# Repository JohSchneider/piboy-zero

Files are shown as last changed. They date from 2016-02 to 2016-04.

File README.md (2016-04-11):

# Pi-Boy Zero
aka "PiGrrl-Zero"

[hackaday.io project](https://hackaday.io/project/9467-pigrrl-zero)

*yet another portable console! ;-)*

roughly the size of a gameboy micro, with a 2.2" display

this repository holds:
- the pcb-schematics (kicad)
- stl files for a 3d printable case
- and various setup scripts/tools/config-files to get emulationstation running on this particular hardware setup

## the progress so far
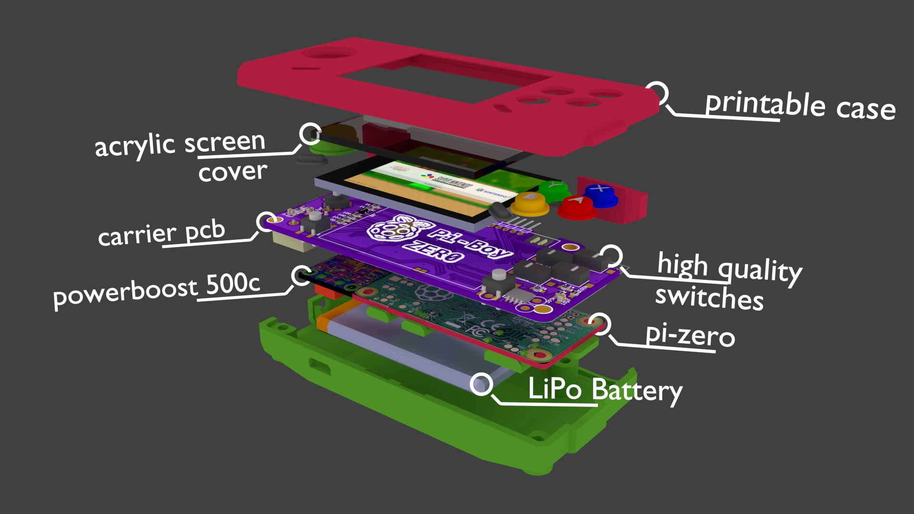
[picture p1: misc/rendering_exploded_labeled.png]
rendering of how the components are assembled

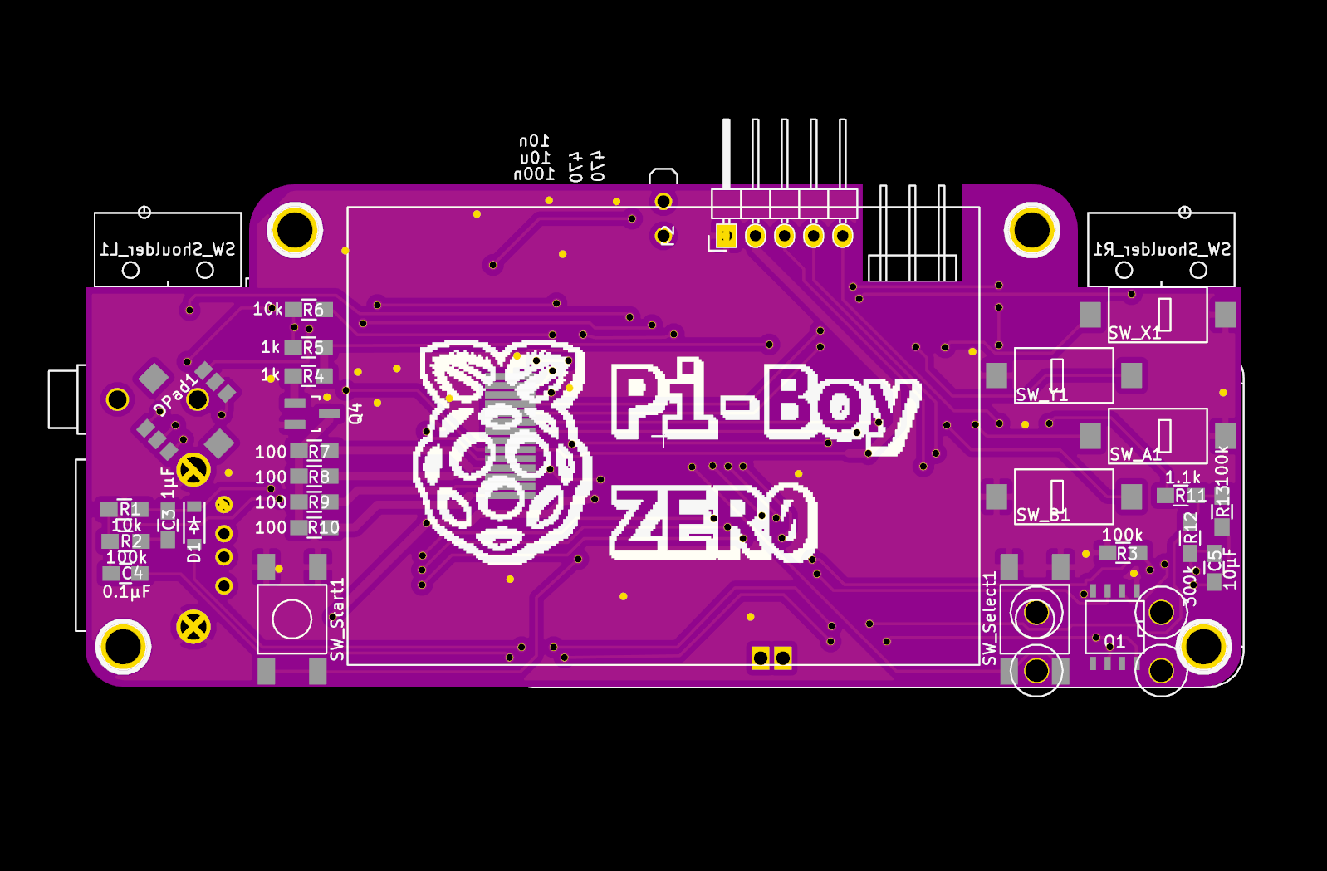
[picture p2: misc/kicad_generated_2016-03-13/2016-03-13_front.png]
front face of the carrier pcb

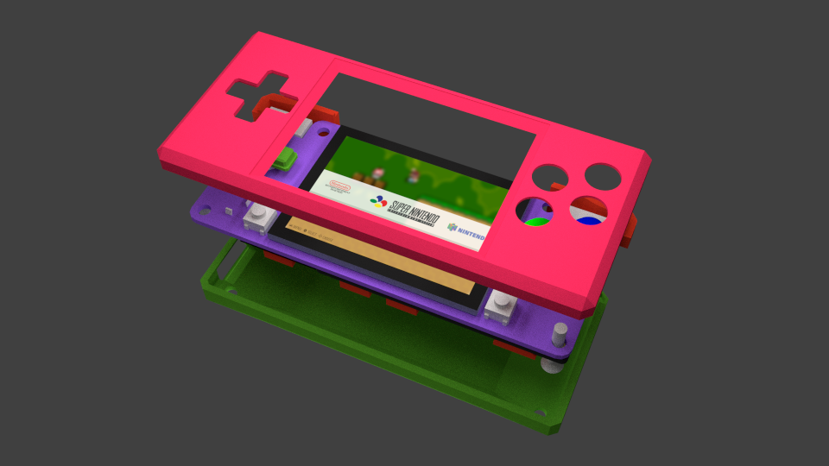
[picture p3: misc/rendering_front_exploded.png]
rendering of what the 3d printed case will look like

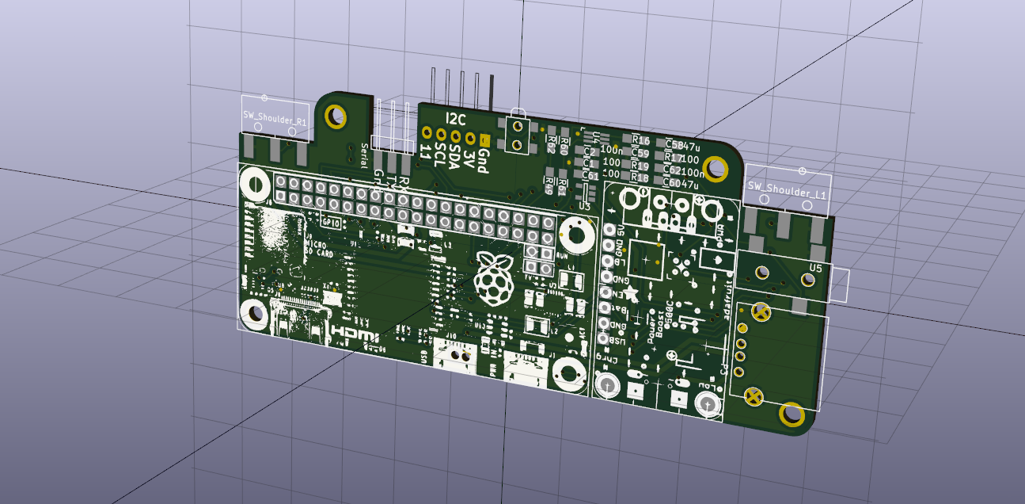
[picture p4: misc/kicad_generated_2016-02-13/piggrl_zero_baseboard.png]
kicad rendering of the baseboard


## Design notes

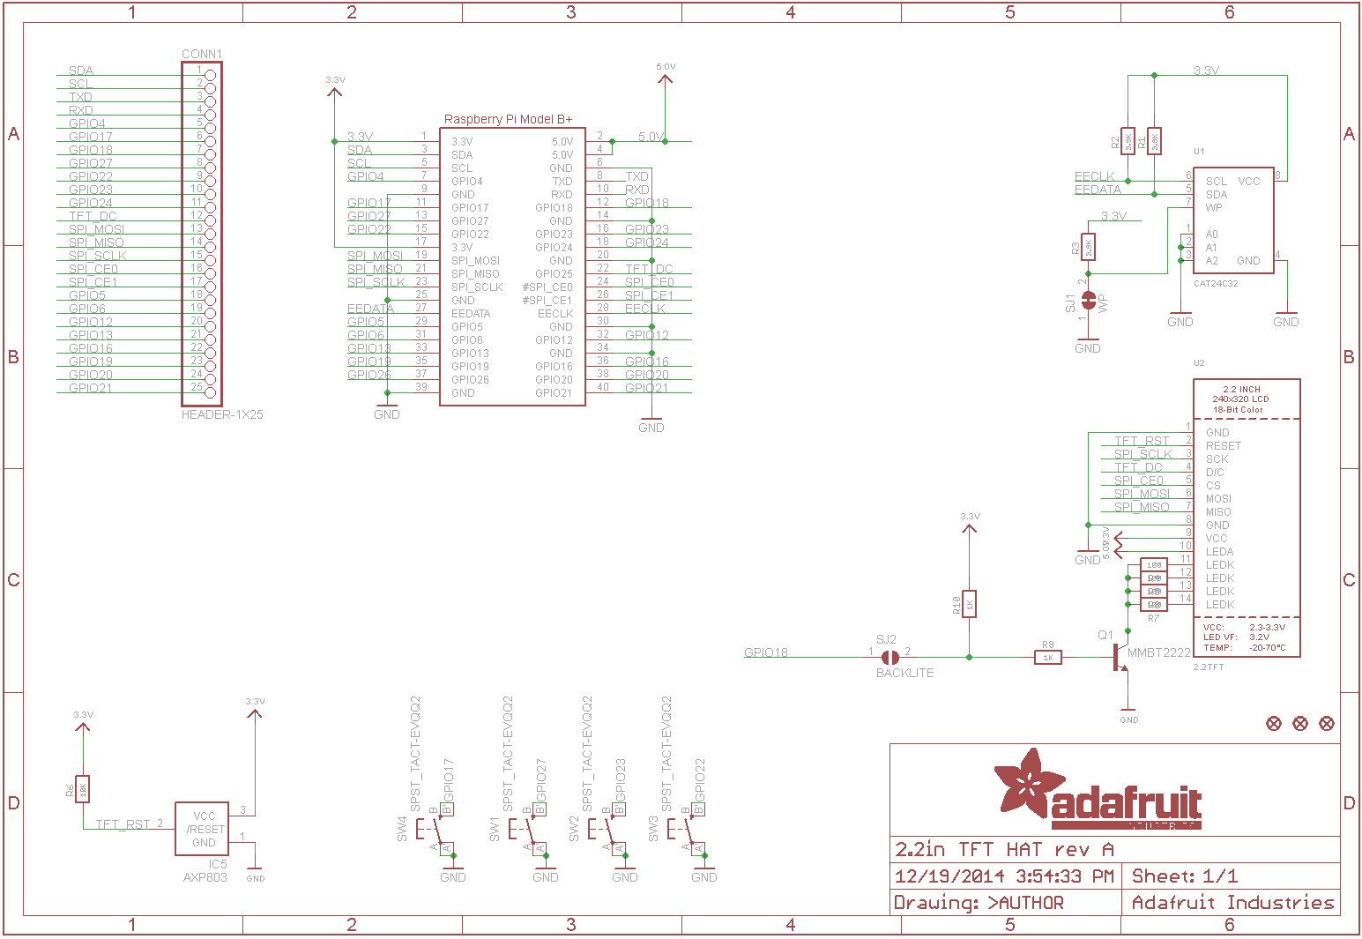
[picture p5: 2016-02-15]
source_schematics/pitftf_2.2inch_hat.png

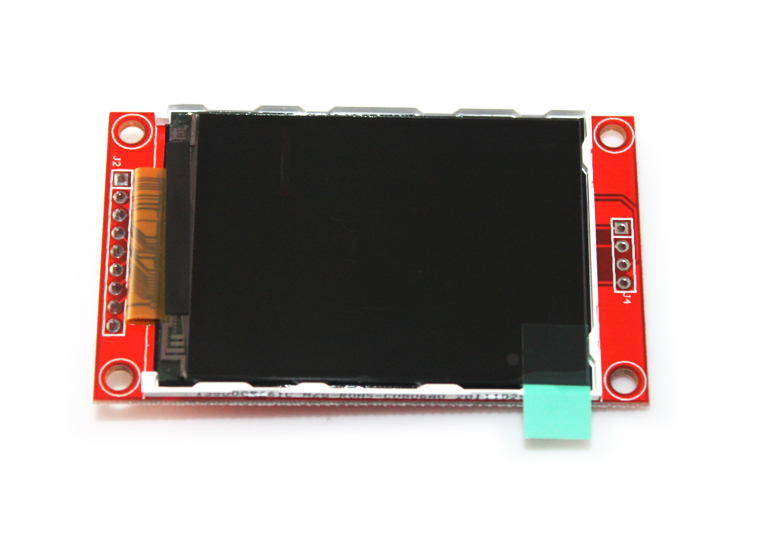
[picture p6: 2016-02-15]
source_schematics/2.2S/2.2SP_A.JPG

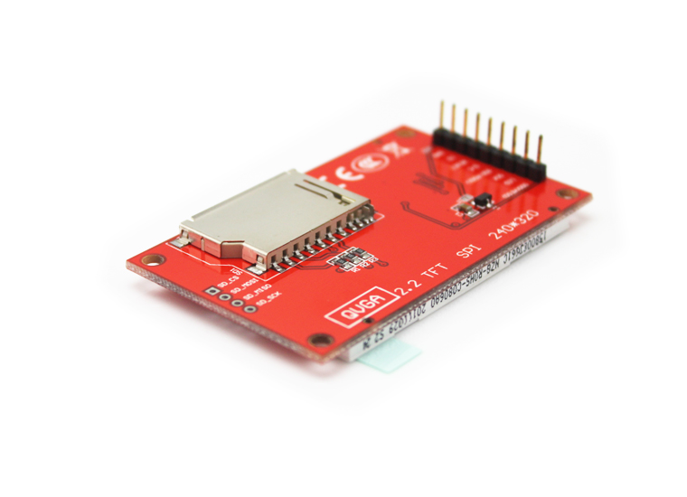
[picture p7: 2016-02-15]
source_schematics/2.2S/2.2SP_C.jpg

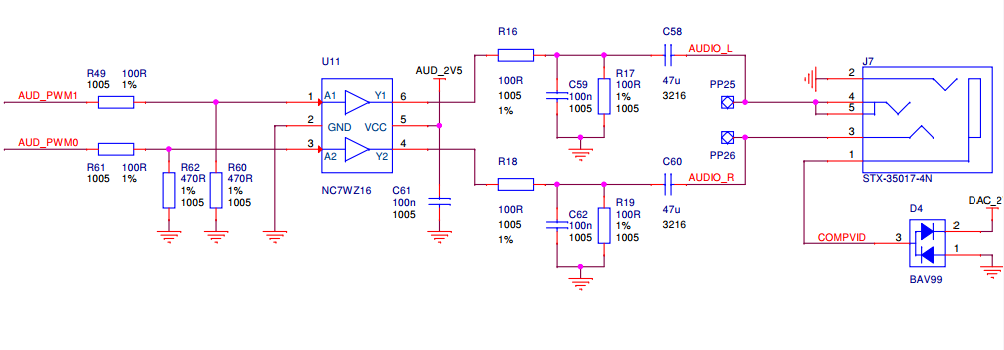
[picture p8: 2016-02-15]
source_schematics/raspberry_B+_pi_audio.png

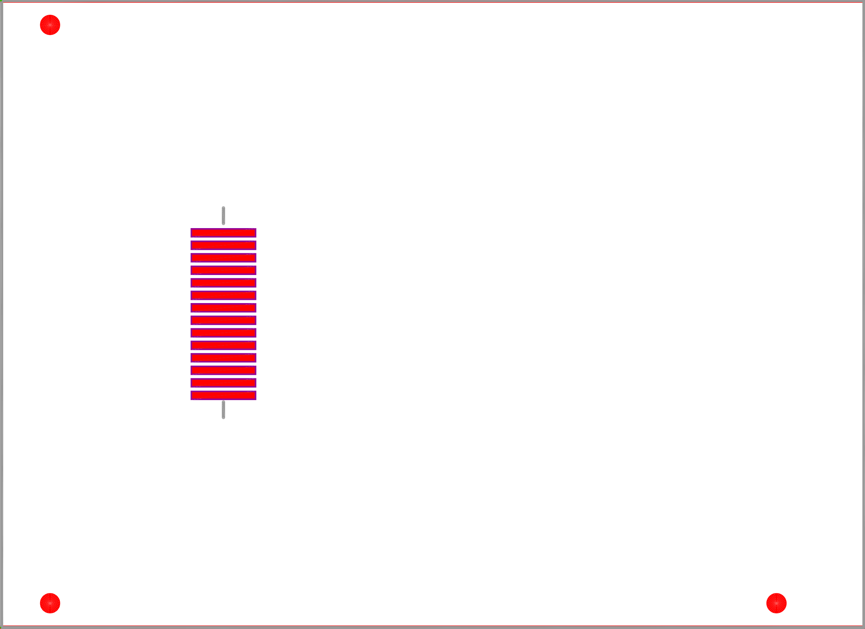
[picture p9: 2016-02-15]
source_schematics/2.2S/Datasheet.png

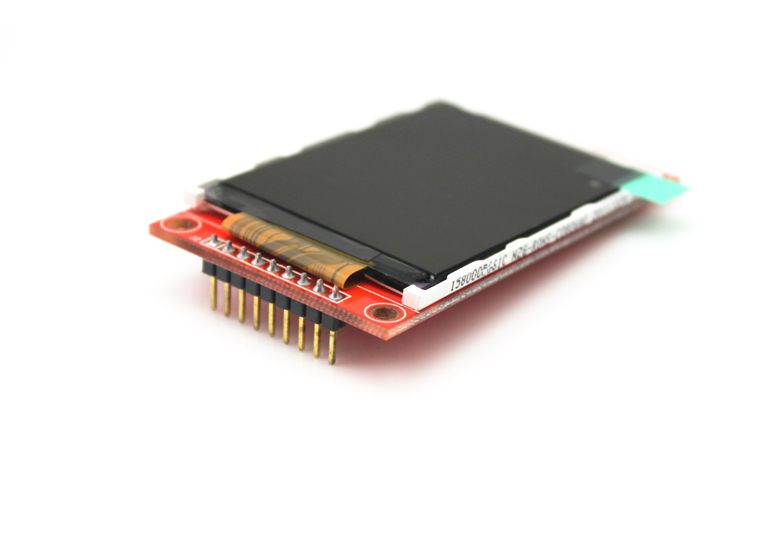
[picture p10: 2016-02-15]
source_schematics/2.2S/2.2SP_B.jpg

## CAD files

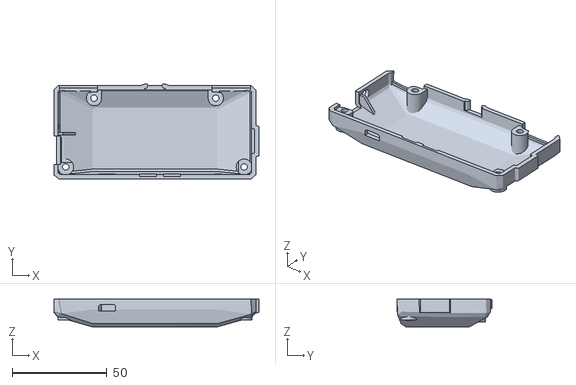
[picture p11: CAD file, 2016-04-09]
enclosure/case_bot.stl
108.5 x 50.1 x 14.6

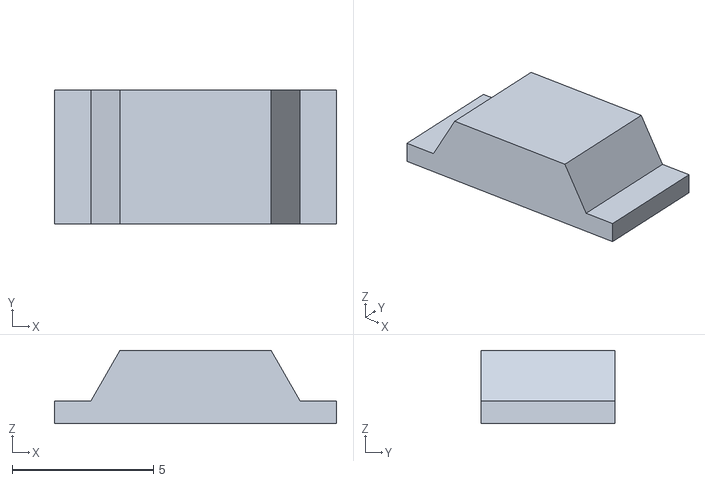
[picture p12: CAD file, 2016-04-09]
enclosure/button_power.stl
10.0 x 4.76 x 2.60

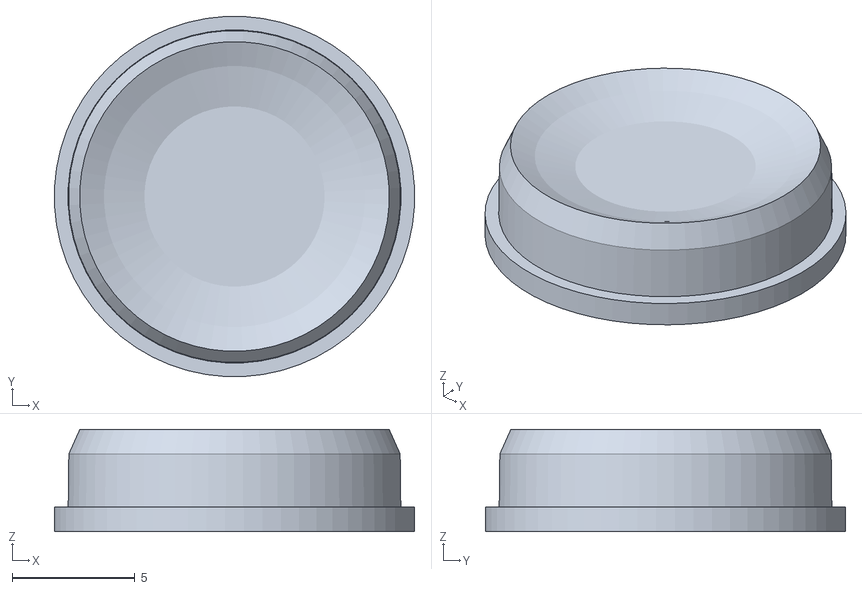
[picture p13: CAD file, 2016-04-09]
enclosure/button_dpad.stl
14.7 x 14.7 x 4.18

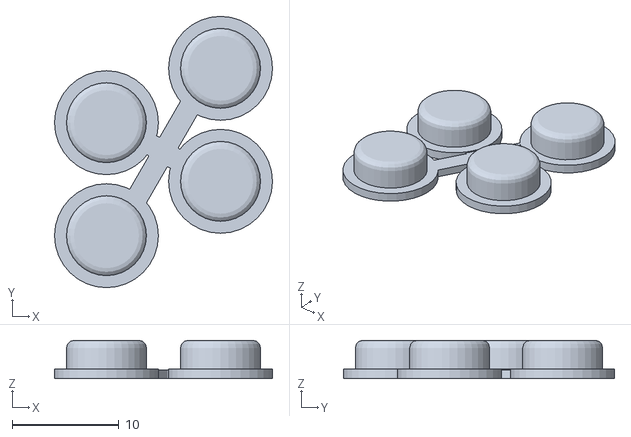
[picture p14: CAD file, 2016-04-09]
enclosure/button_ABXY.stl
20.5 x 25.5 x 3.60

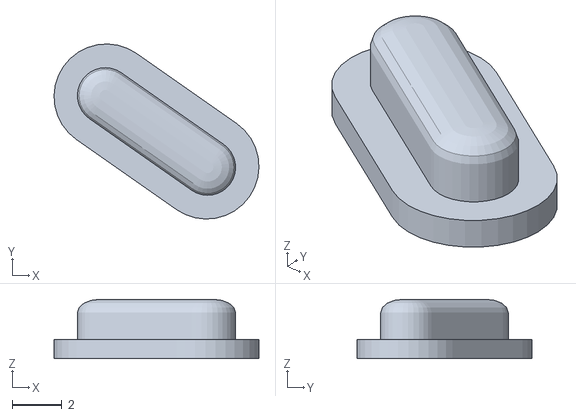
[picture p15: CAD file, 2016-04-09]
enclosure/button_start_select.stl
8.21 x 7.01 x 2.38

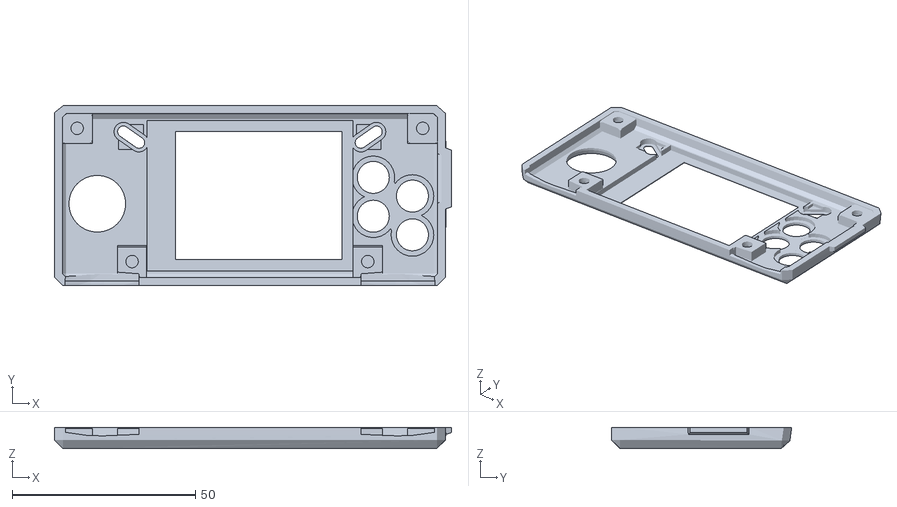
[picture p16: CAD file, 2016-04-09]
enclosure/case_top.stl
108.5 x 49.3 x 5.80

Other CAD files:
source_schematics/2.2S/51-keil-Demo/Integrated_Test_requires_more_than_16K_ROM_MCU/Integrated_Test_requires_more_than_16K_ROM_MCU/main.OBJ
source_schematics/2.2S/51-keil-Demo/Basic_scrap_r test/main.OBJ
source_schematics/2.2S/51-keil-Demo/Basic_scrap_r test/touch.obj
source_schematics/2.2S/51-keil-Demo/Basic_scrap_r test/STARTUP.OBJ
source_schematics/2.2S/51-keil-Demo/Integrated_Test_requires_more_than_16K_ROM_MCU/Integrated_Test_requires_more_than_16K_ROM_MCU/STARTUP.OBJ
source_schematics/2.2S/51-keil-Demo/Basic_scrap_r test/font.obj
source_schematics/2.2S/51-keil-Demo/Integrated_Test_requires_more_than_16K_ROM_MCU/Integrated_Test_requires_more_than_16K_ROM_MCU/sys.obj
source_schematics/2.2S/51-keil-Demo/Basic_scrap_r test/sys.obj
source_schematics/2.2S/51-keil-Demo/Integrated_Test_requires_more_than_16K_ROM_MCU/Integrated_Test_requires_more_than_16K_ROM_MCU/touch.obj
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

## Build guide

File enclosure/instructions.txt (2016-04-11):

- prints well on a FDM-type printer (and probably on SLS/SLA/... as well :-)
  what worked for me:
  0.25mm nozzle
  0.1mm layer height, 0.25mm extrusion width for the buttons
  0.2mm layer height, 0.5mm extrusion width for the case

- only the back piece needs generated support structures, all other parts can be printed without

- the two case halfes are held together with M3x16 countersunk screws and M3 nuts

- the M3 captive-nuts are designed to be inserted during the print (pause, push in, resume)

- the screen has a piece of acrylic as protective cover, which measures: 55mm x 40mm x 2mm

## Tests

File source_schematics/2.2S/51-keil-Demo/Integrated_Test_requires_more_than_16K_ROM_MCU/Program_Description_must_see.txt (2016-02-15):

测试程序功能
开机显示中文，英文，图片

修改LCD数据脚连接IO在lcd.h文件中
40*40图片数据和95个ASCCII字符数据和测试汉字取模数据在font.c文件中

/* 
程序默认IO连接方式：
sbit LCD_CS     =P0^0;     //片选	
sbit LCD_DC     =P0^2;	  //数据/命令切换
sbit LCD_SDI    =P1^5;	  //数据
sbit LCD_SCK    =P1^7;	  //时钟
sbit LCD_REST   =P0^1;	  //复位  
*/

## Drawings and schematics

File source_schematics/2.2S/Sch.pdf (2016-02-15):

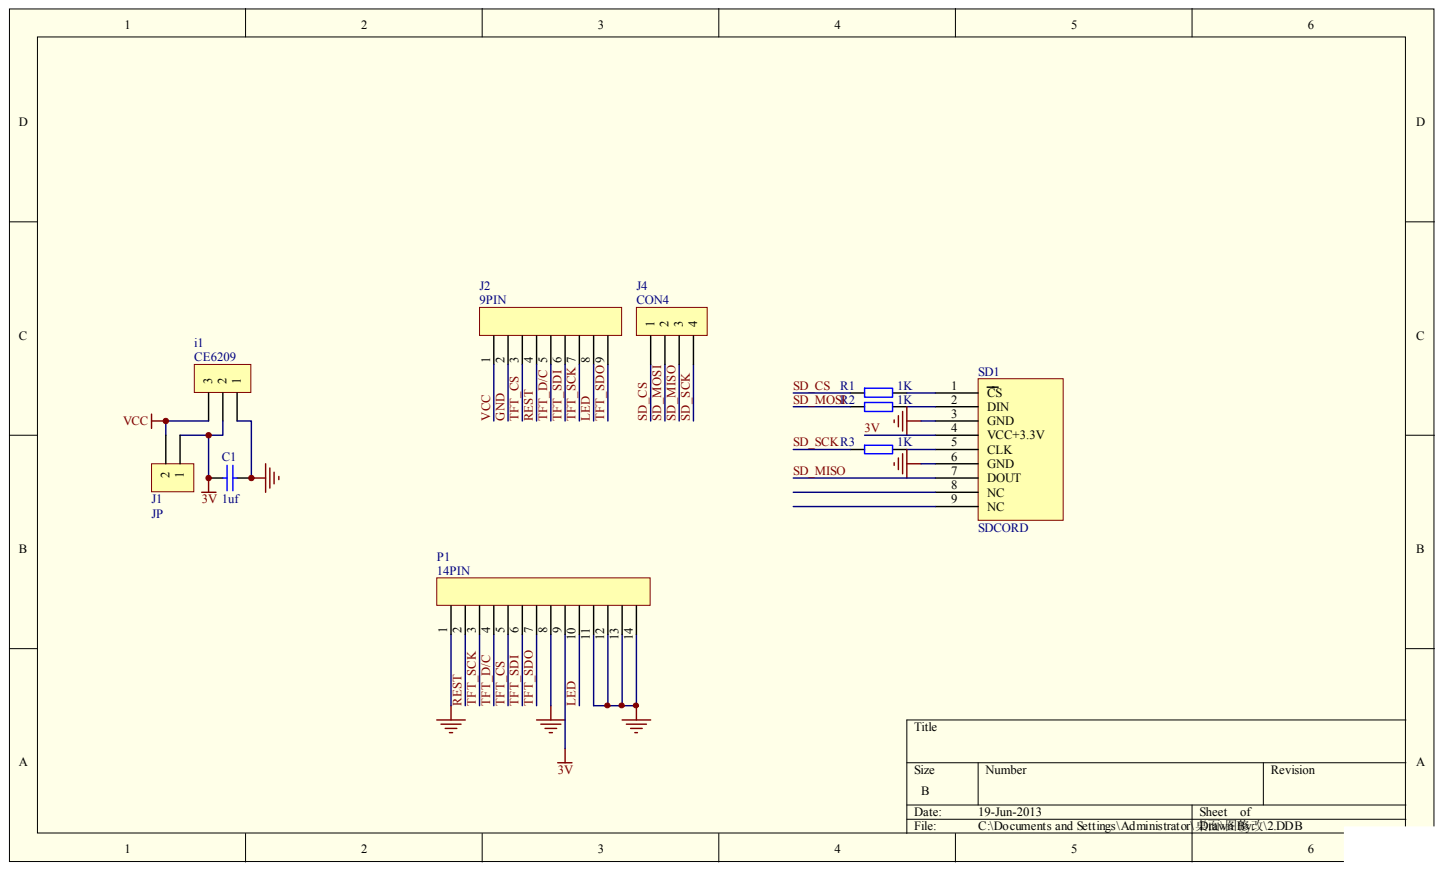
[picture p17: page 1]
Title; Size; Number; Revision; Date:; 19-Jun-2013; Sheet of File:; C:\Documents and Settings\Administrator\桌D面raw\图n B修y改: \2.DDB; DIN; GND; VCC+3.3V; CLK; DOUT; SDCORD; TFT_SDO; J2 9PIN; LED; SD_MOSI; SD_SCK; TFT_SDI TFT_CS TFT_D/C; TFT_SCK; REST; SD_MISO; P1 14PIN; TFT_CS; TFT_SDI; J4CON4; TFT_D/C; VCC GND; VCC

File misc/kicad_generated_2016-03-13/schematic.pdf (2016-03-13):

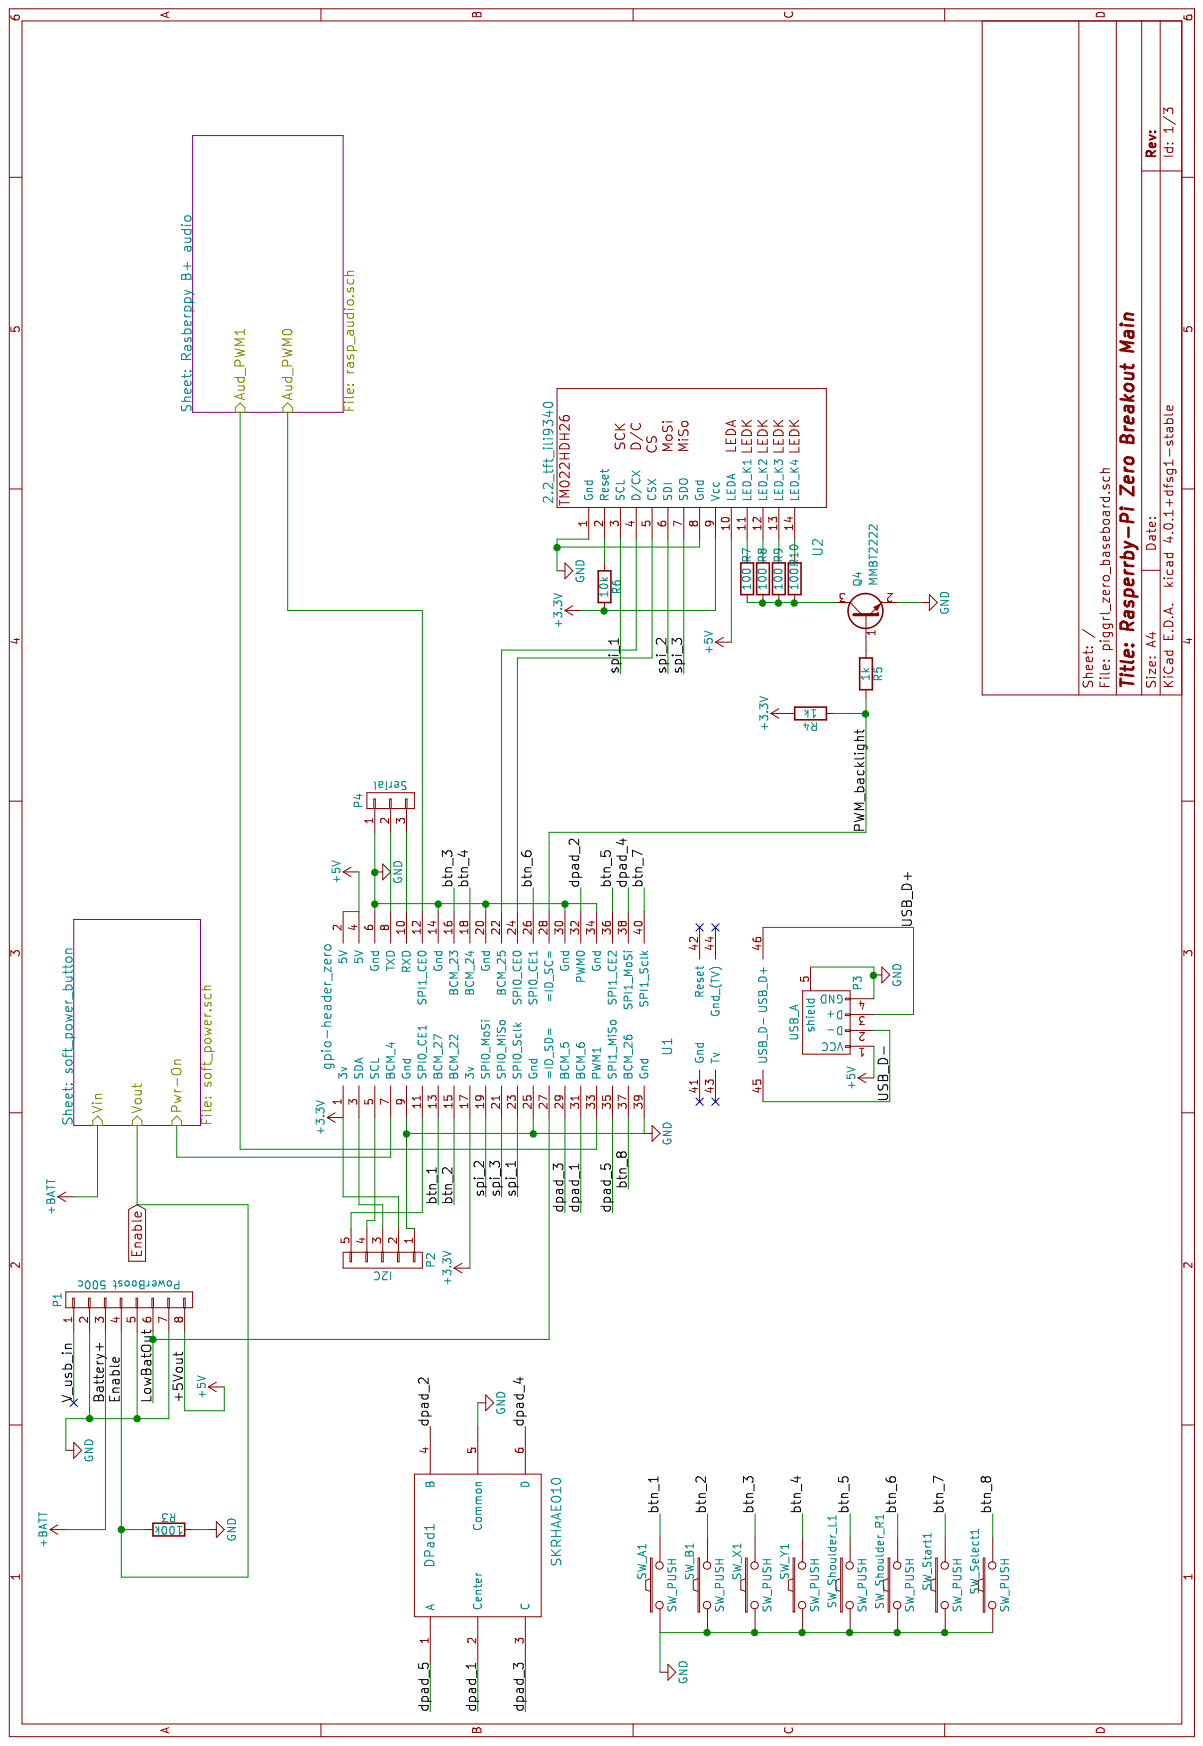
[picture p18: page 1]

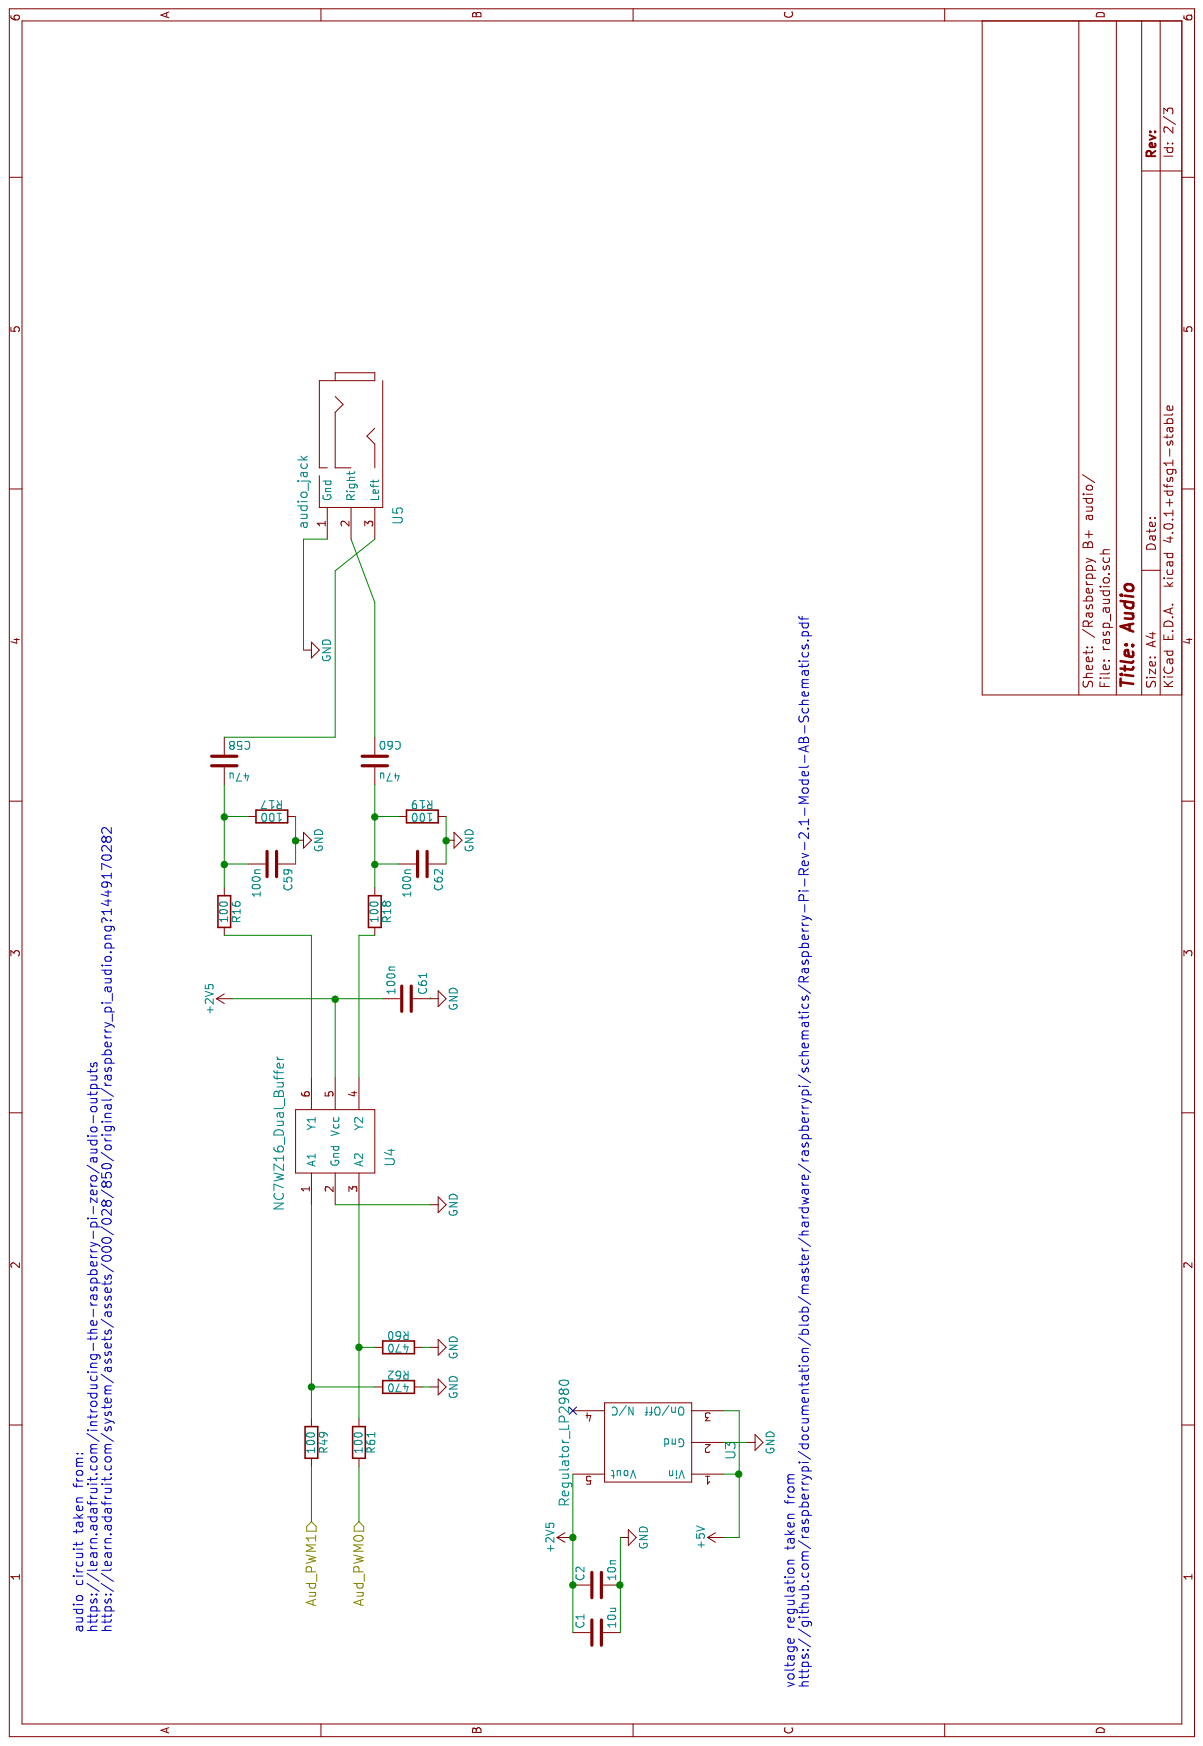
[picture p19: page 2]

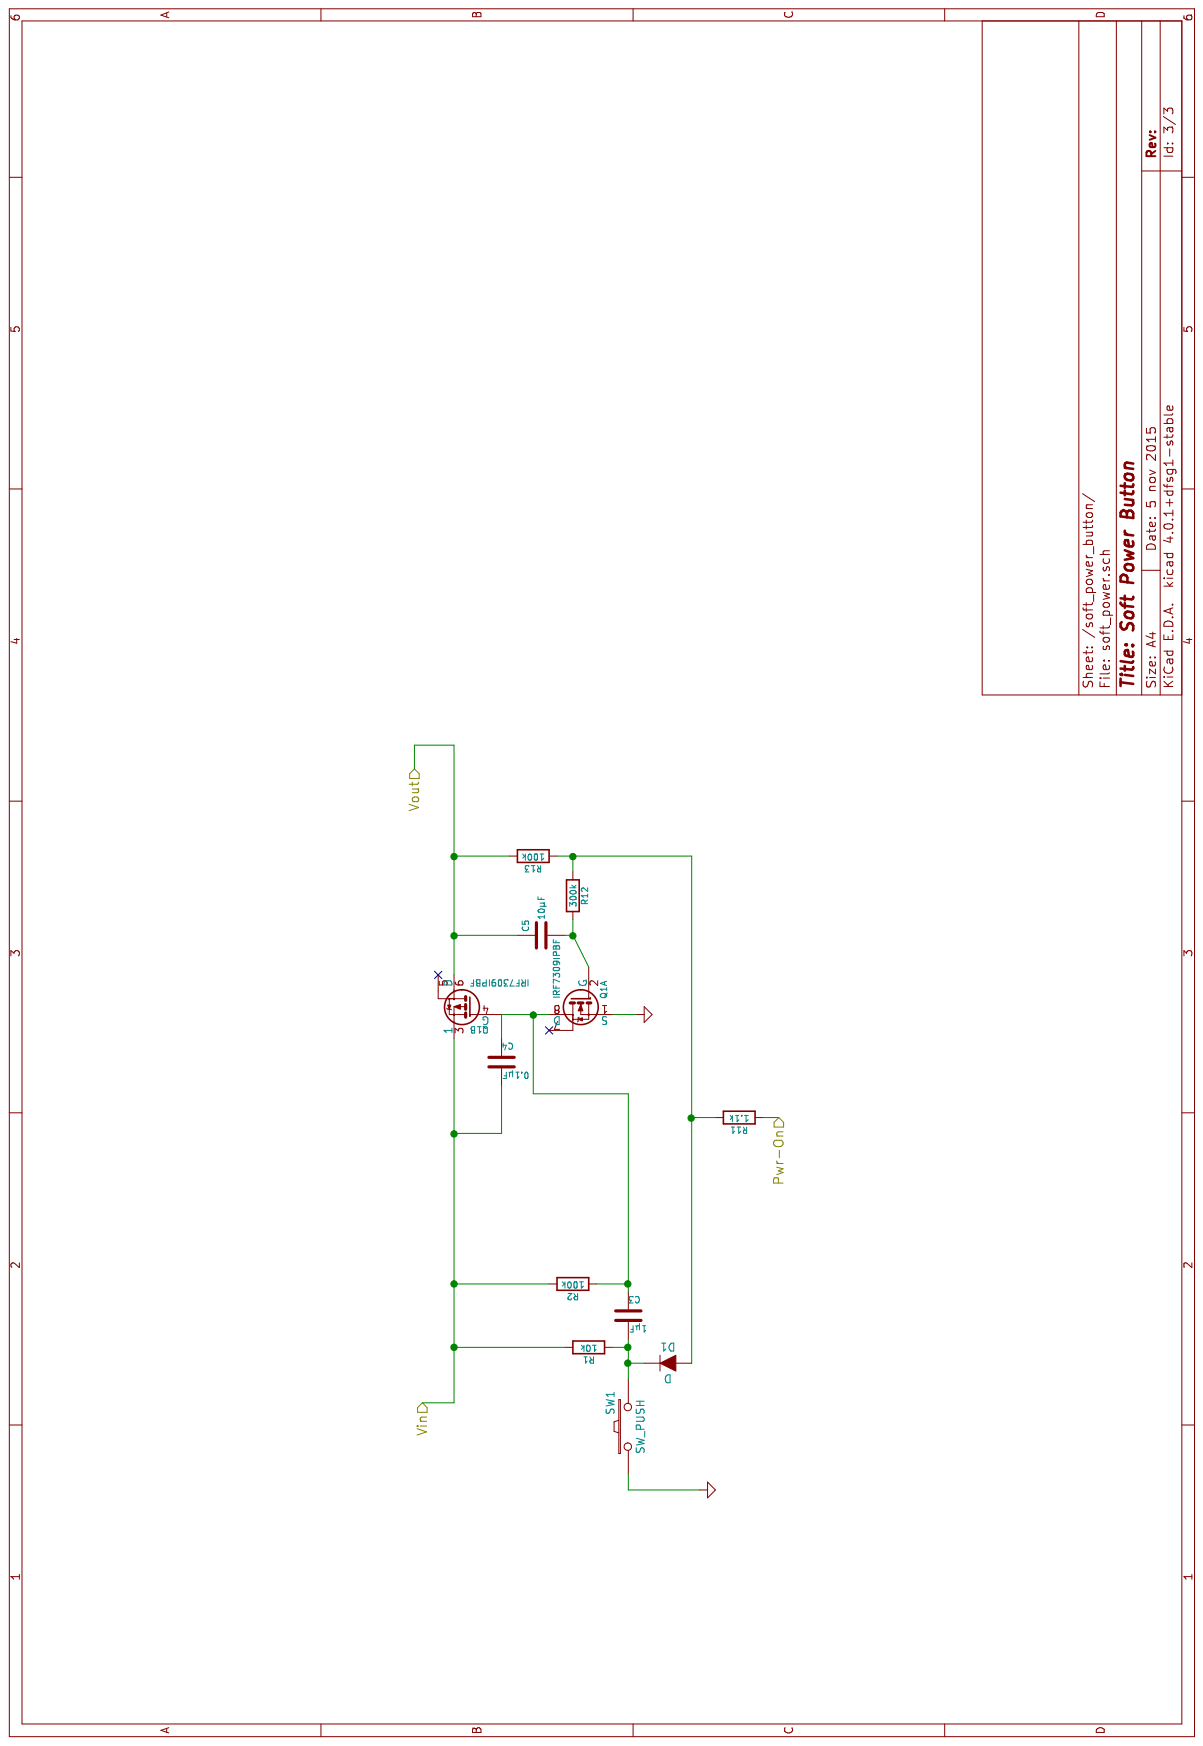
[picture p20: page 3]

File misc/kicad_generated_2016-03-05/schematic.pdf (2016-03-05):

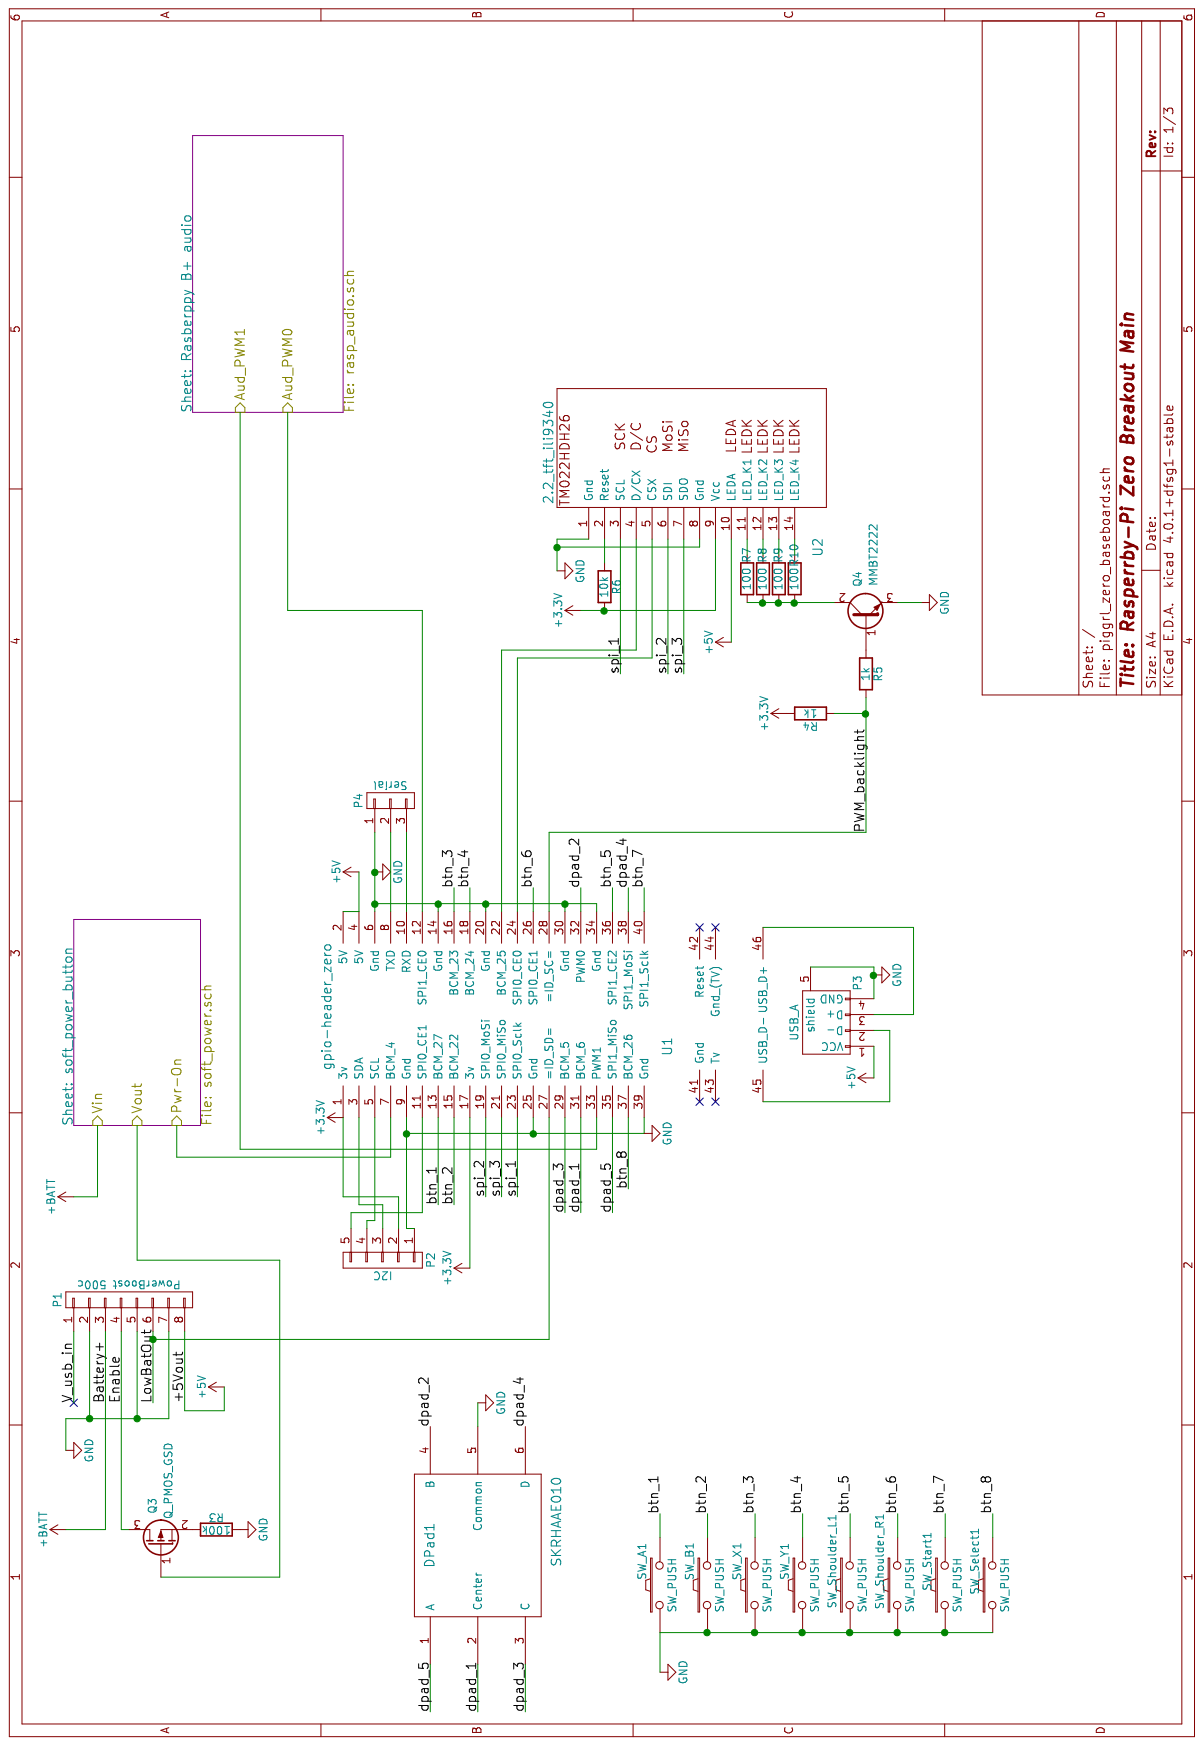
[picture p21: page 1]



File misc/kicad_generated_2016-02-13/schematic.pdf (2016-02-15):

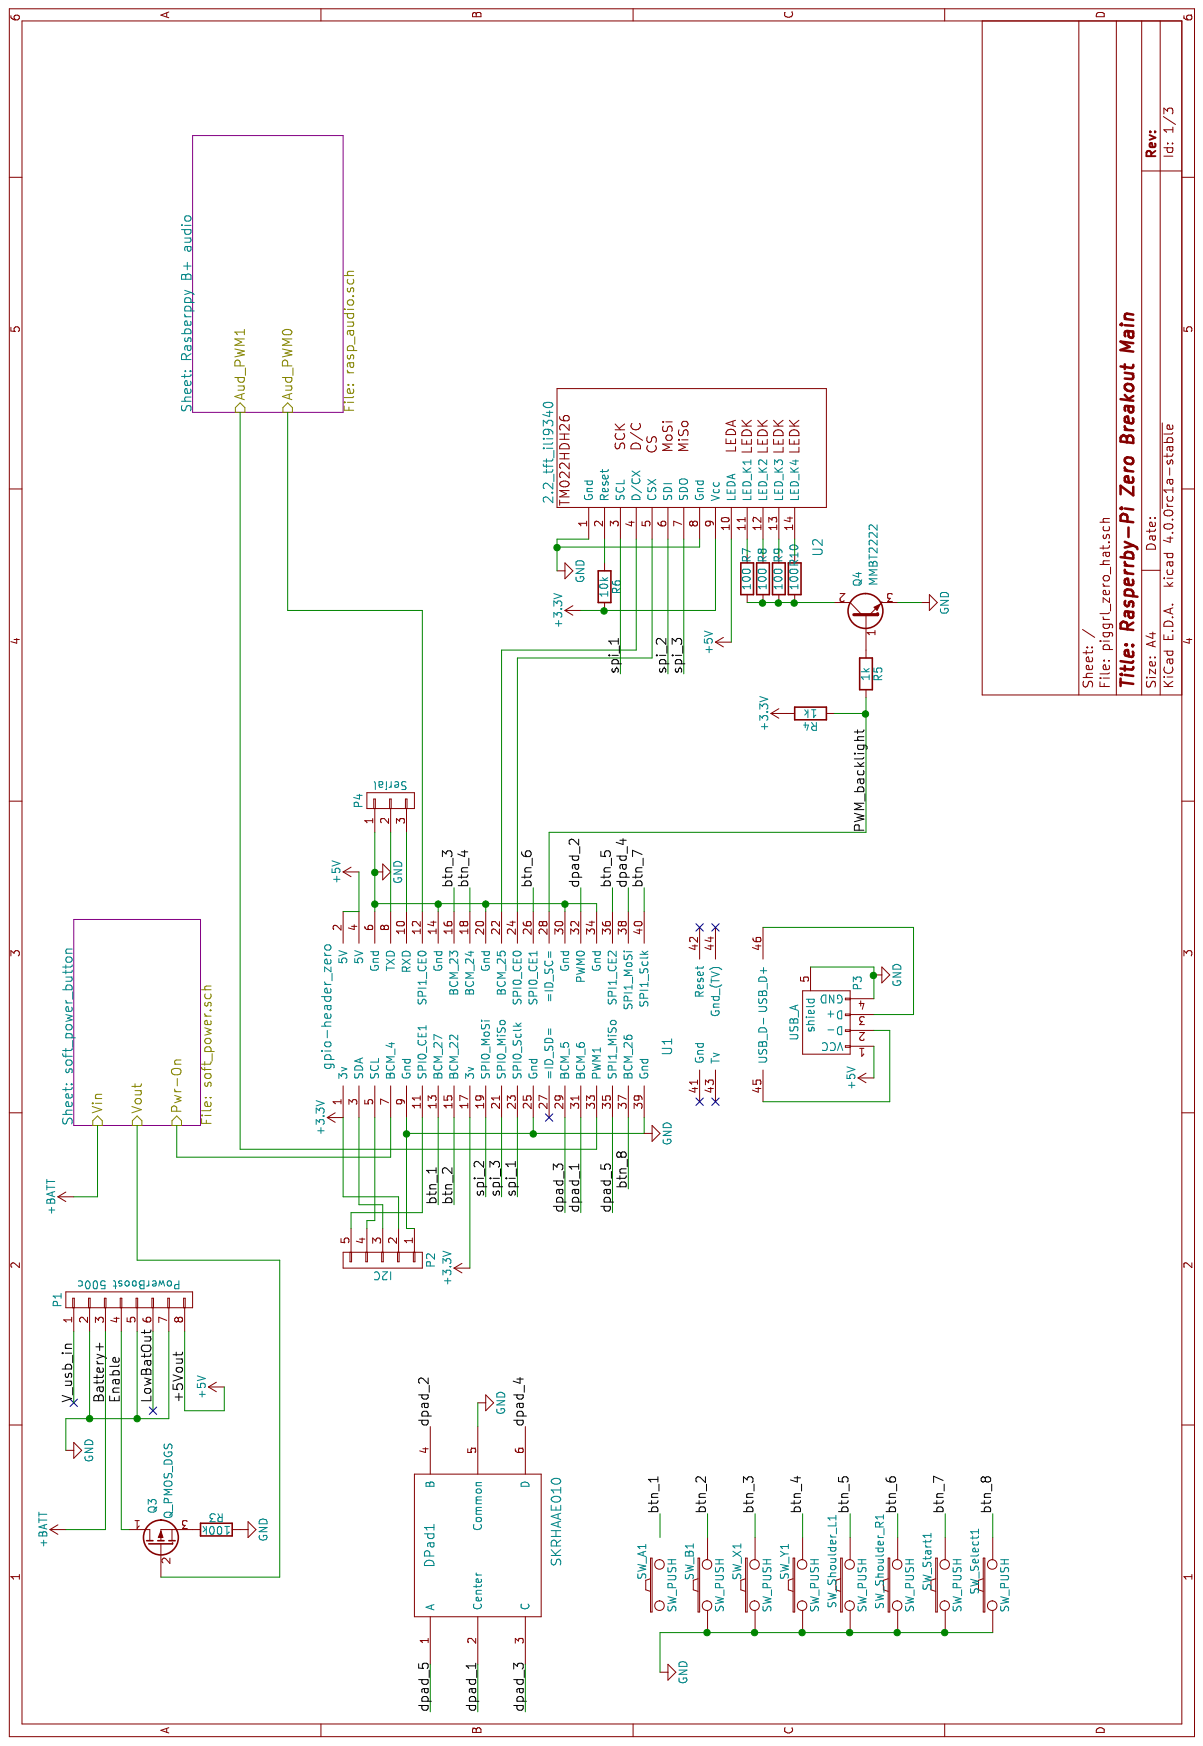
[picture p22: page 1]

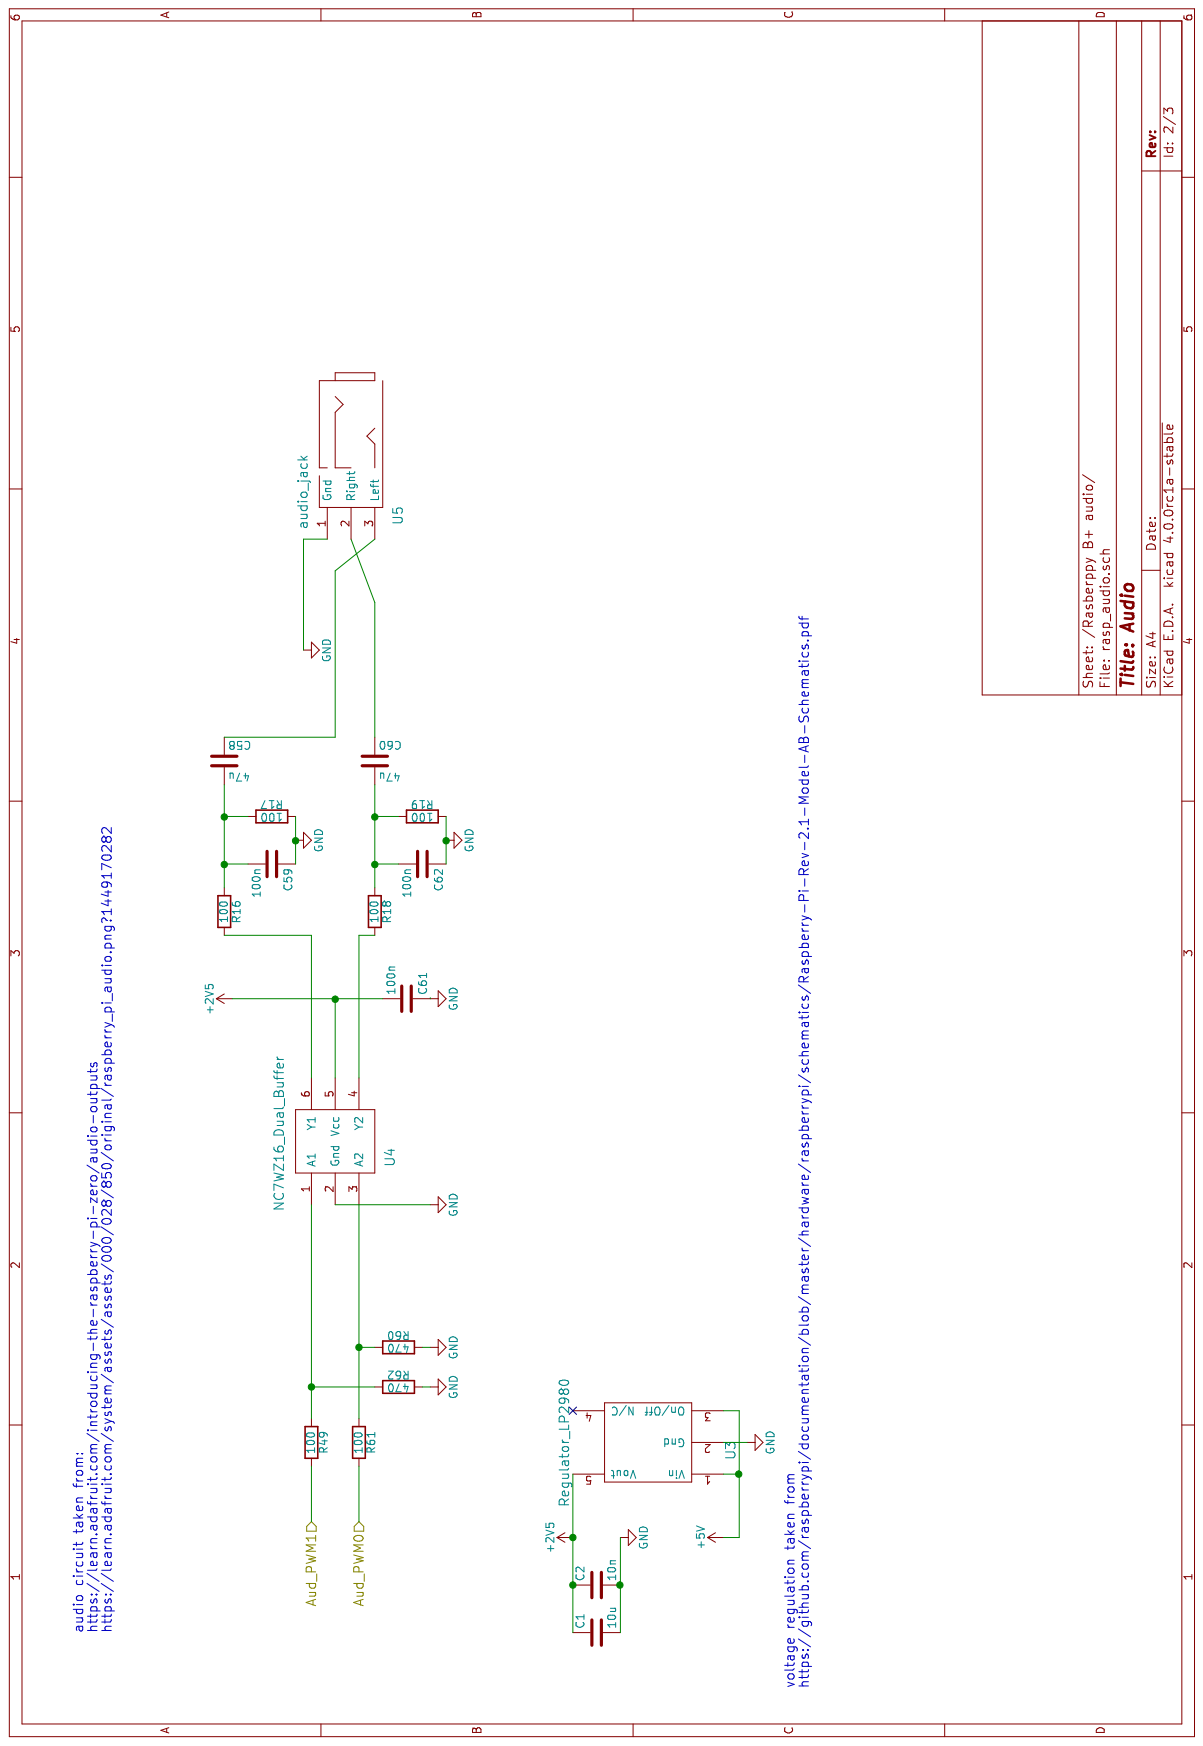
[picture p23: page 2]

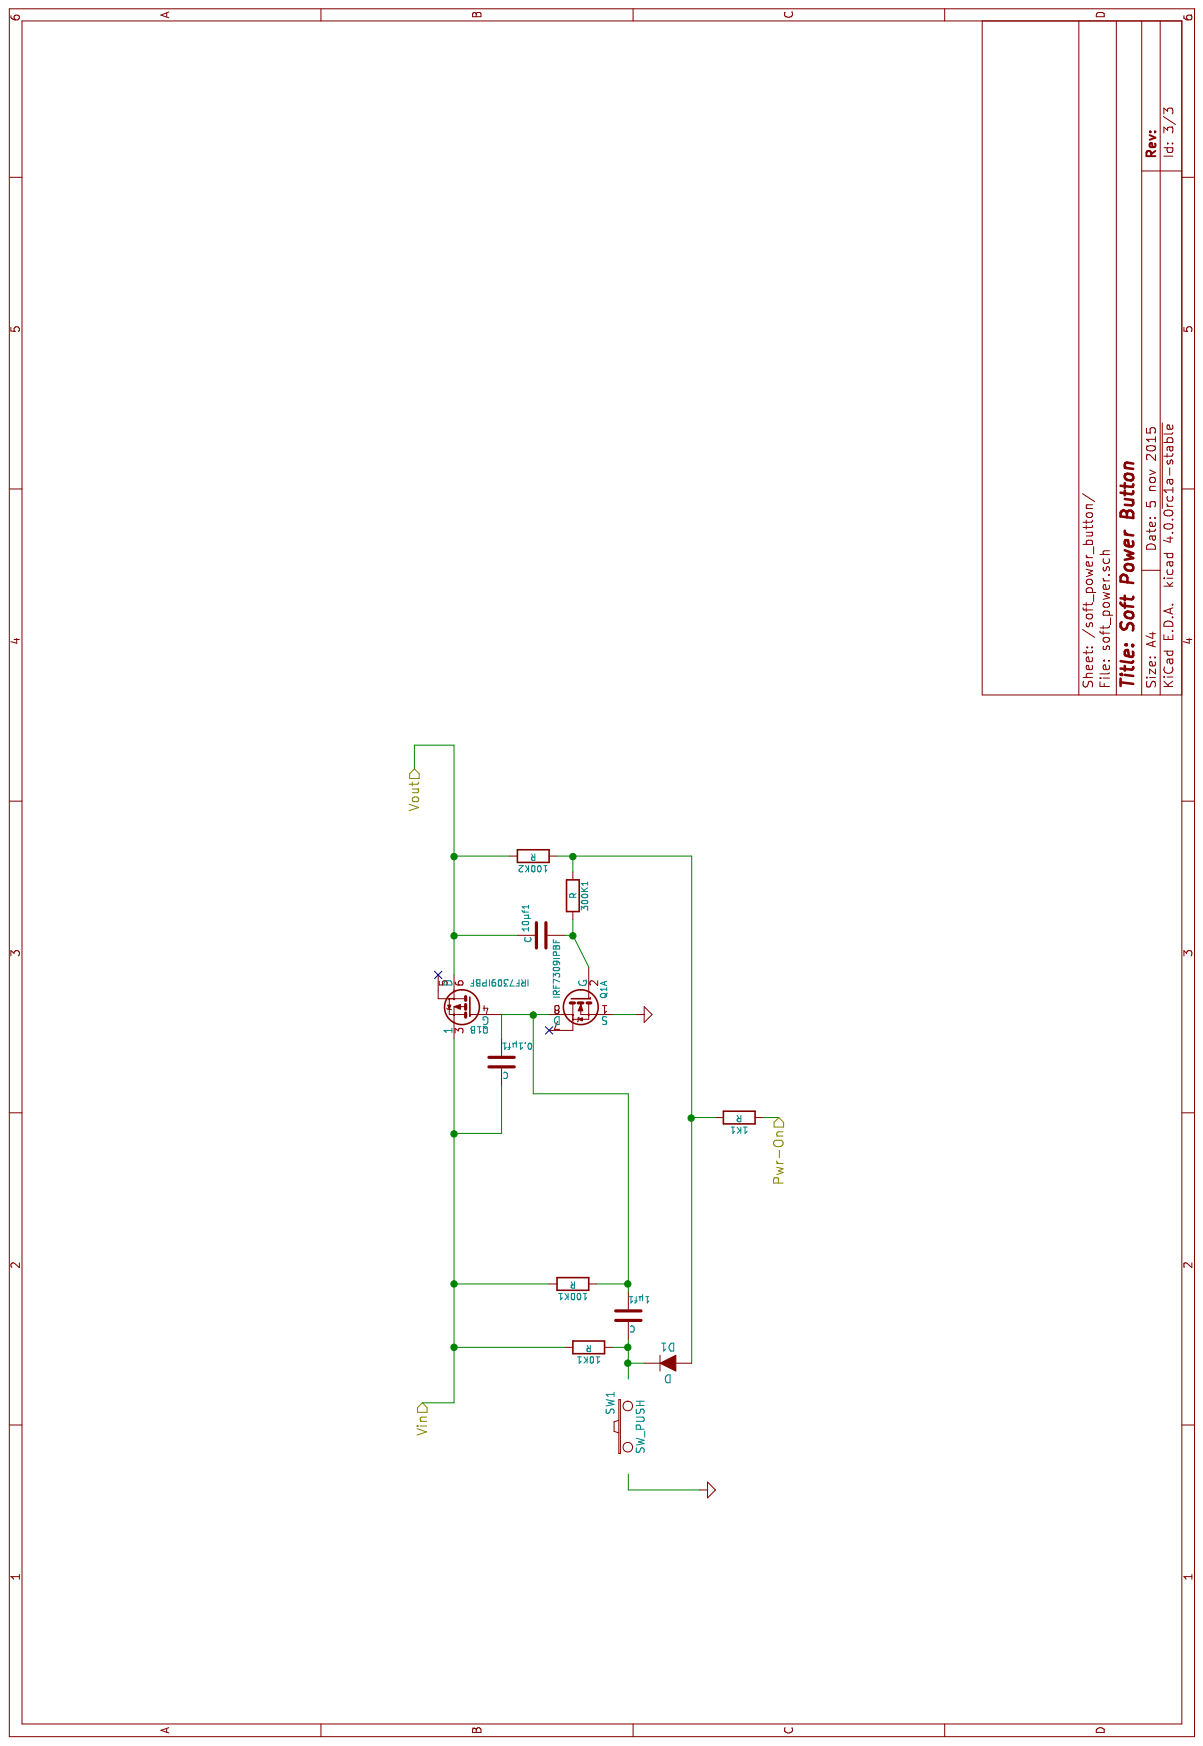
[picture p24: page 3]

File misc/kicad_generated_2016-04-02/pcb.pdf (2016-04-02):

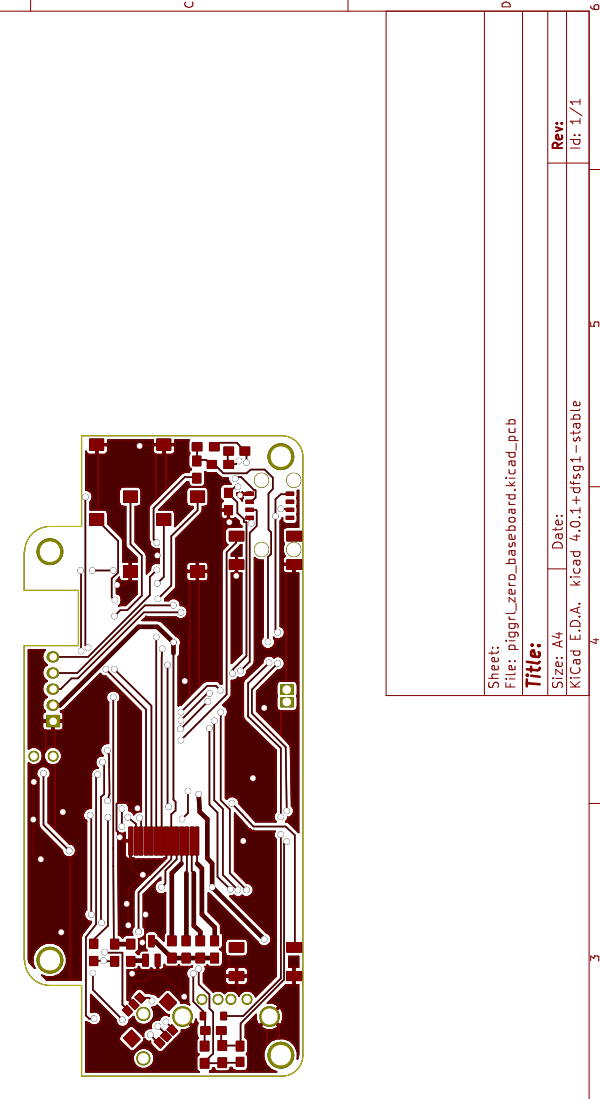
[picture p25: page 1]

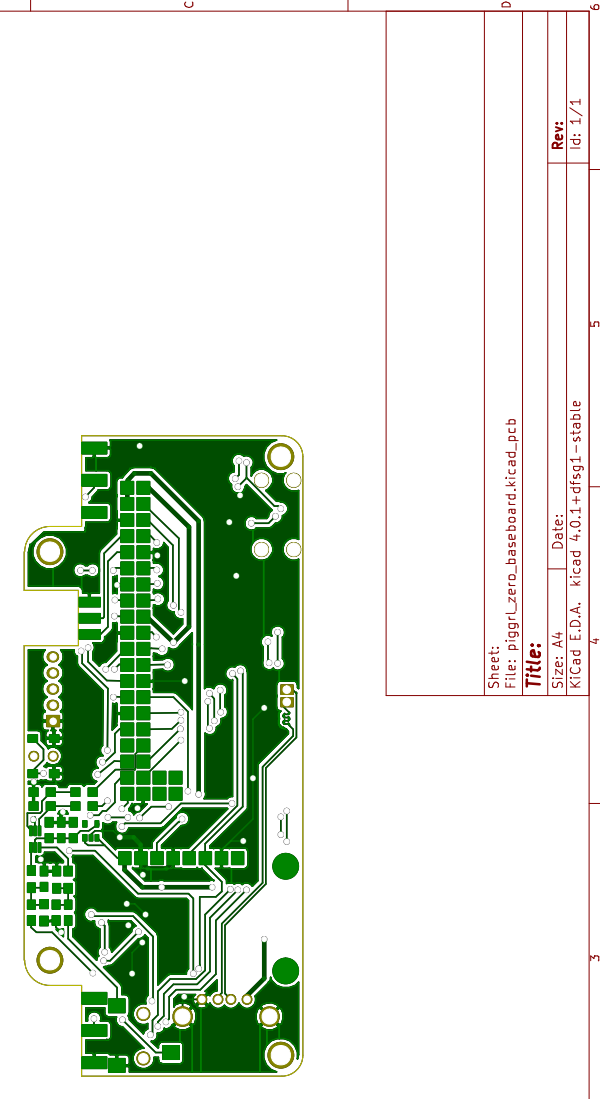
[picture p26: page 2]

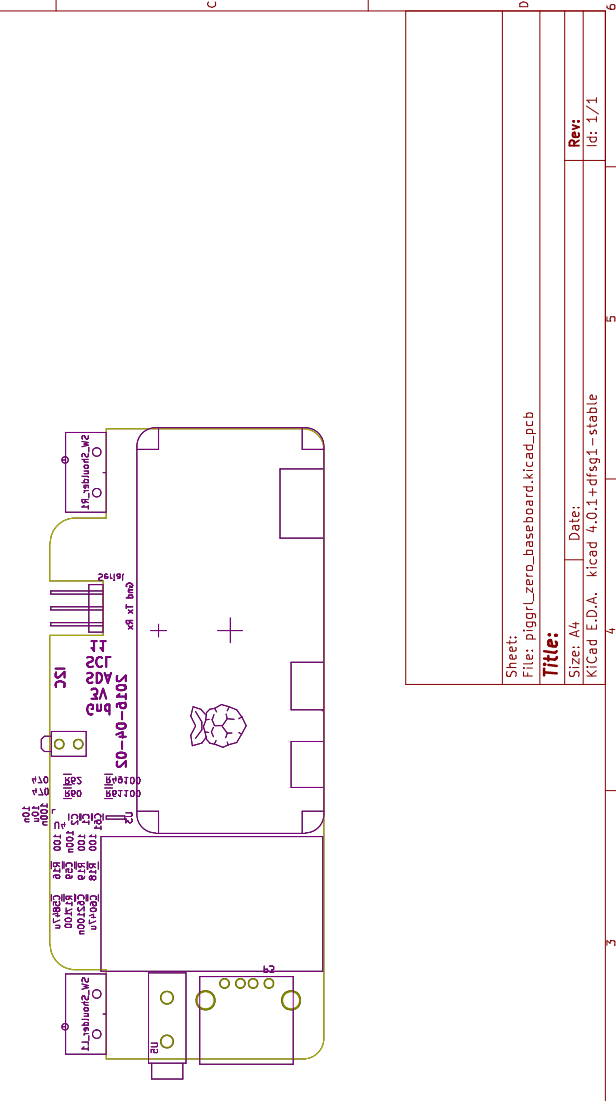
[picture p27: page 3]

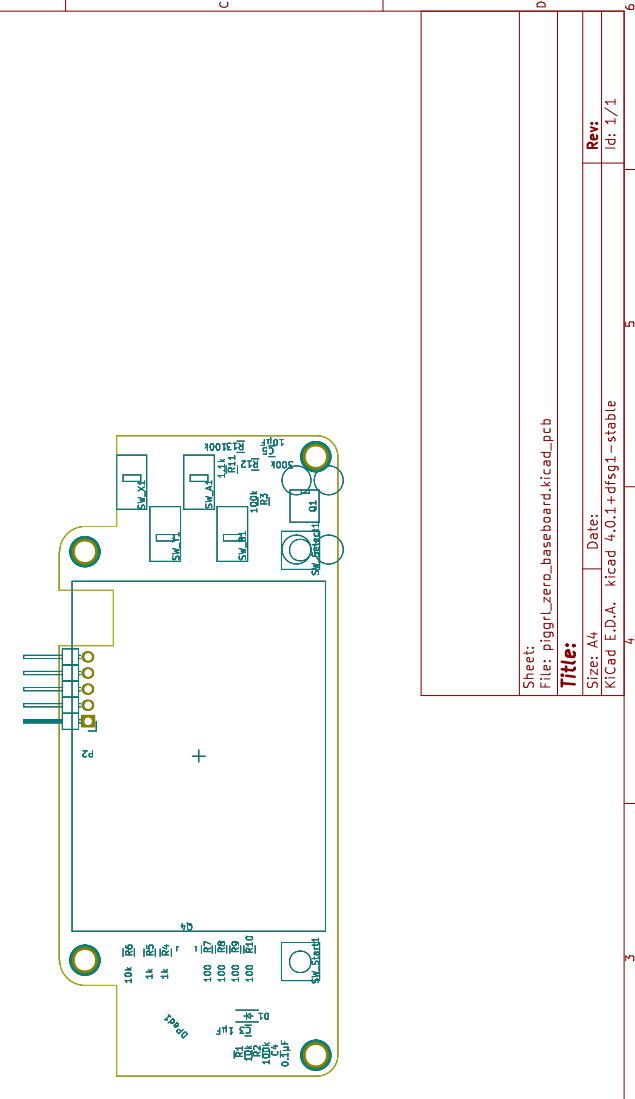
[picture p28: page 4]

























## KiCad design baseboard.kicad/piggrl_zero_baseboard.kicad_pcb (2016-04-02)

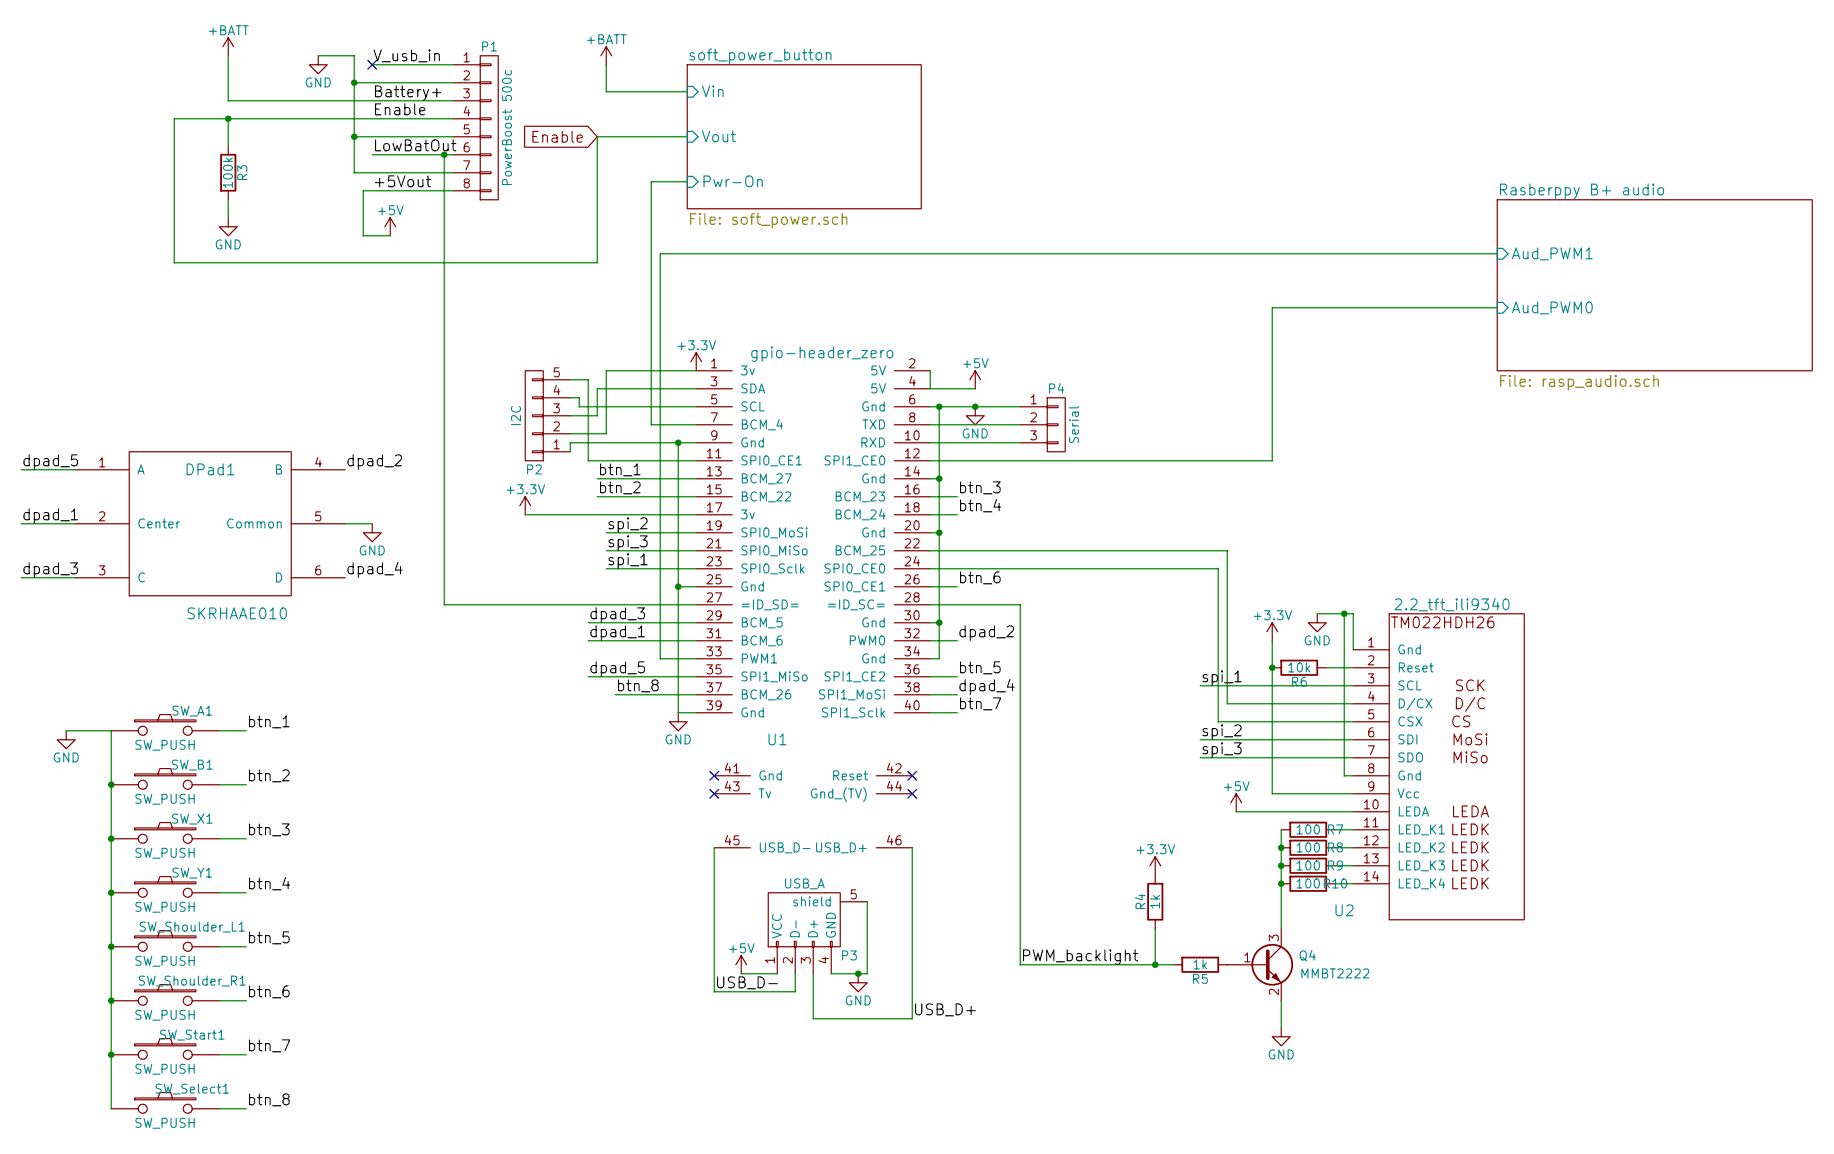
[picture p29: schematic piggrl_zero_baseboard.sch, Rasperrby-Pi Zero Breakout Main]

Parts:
DPad1: SKRHAAE010; ManufacturerPartNumber SKRHAAE010
P1: PowerBoost 500c; Powerboost500c
P2: I2C; Pin_Header_Angled_1x05
P3: USB_A
P4: Serial; 1x3_smd_pinheader
Q4: MMBT2222; SOT-23_Handsoldering; ManufacturerPartNumber MMBT2222ALT1G
R3: 100k; R_0805_HandSoldering; ManufacturerPartNumber ERJ-6ENF1003V
R4, R5: 1k; R_0805_HandSoldering; ManufacturerPartNumber ERJ-6ENF1001V
R6: 10k; R_0805_HandSoldering; ManufacturerPartNumber ERJ-6ENF1002V
R7, R8, R9, R10: 100; R_0805_HandSoldering; ManufacturerPartNumber ERJ-6ENF1000V
SW_A1: SW_PUSH; Omron_D2LS_21_woKeyHoles; ManufacturerPartNumber D2LS-21
SW_B1: SW_PUSH; Omron_D2LS_21_woKeyHoles; ManufacturerPartNumber D2LS-21
SW_Select1: SW_PUSH; smd_push_button; ManufacturerPartNumber 2-1437565-8
SW_Shoulder_L1: SW_PUSH; Omron_D2FS_FTN_mirror; ManufacturerPartNumber D2FS-F-N-T
SW_Shoulder_R1: SW_PUSH; Omron_D2FS_FTN; ManufacturerPartNumber D2FS-F-N-T
SW_Start1: SW_PUSH; smd_push_button; ManufacturerPartNumber 2-1437565-8
SW_X1: SW_PUSH; Omron_D2LS_21_woKeyHoles; ManufacturerPartNumber D2LS-21
SW_Y1: SW_PUSH; Omron_D2LS_21_woKeyHoles; ManufacturerPartNumber D2LS-21
U1: gpio-header_zero; raspberry-zero
U2: 2.2_tft_ili9340; TM022HDH26

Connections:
+3V3: P2.2, R4.2, R6.2, U1.1 (3v), U1.17 (3v), U2.9 (Vcc)
+5V: P1.8, P3.1 (VCC), U1.2 (5V), U1.4 (5V), U2.10 (LEDA); also elsewhere on the board
+BATT: P1.3; also elsewhere on the board
/LowBatOut: P1.6, U1.27 (=ID_SD=)
/PWM_backlight: R4.1, R5.2, U1.28 (=ID_SC=)
/Rasberppy B+ audio/Aud_PWM0: U1.12 (SPI1_CE0); also elsewhere on the board
/Rasberppy B+ audio/Aud_PWM1: U1.33 (PWM1); also elsewhere on the board
/USB_D+: P3.3 (D+), U1.46 (USB_D+)
/USB_D-: P3.2 (D-), U1.45 (USB_D-)
/V_usb_in: P1.1
/btn_1: SW_A1.2, U1.13 (BCM_27)
/btn_2: SW_B1.2, U1.15 (BCM_22)
/btn_3: SW_X1.2, U1.16 (BCM_23)
/btn_4: SW_Y1.2, U1.18 (BCM_24)
/btn_5: SW_Shoulder_L1.2, U1.36 (SPI1_CE2)
/btn_6: SW_Shoulder_R1.2, U1.26 (SPI0_CE1)
/btn_7: SW_Start1.2, U1.40 (SPI1_Sclk)
/btn_8: SW_Select1.2, U1.37 (BCM_26)
/dpad_1: DPad1.2 (Center), U1.31 (BCM_6)
/dpad_2: DPad1.4 (B), U1.32 (PWM0)
/dpad_3: DPad1.3 (C), U1.29 (BCM_5)
/dpad_4: DPad1.6 (D), U1.38 (SPI1_MoSi)
/dpad_5: DPad1.1 (A), U1.35 (SPI1_MiSo)
/soft_power_button/Pwr-On: U1.7 (BCM_4); also elsewhere on the board
/spi_1: U1.23 (SPI0_Sclk), U2.3 (SCL)
/spi_2: U1.19 (SPI0_MoSi), U2.6 (SDI)
/spi_3: U1.21 (SPI0_MiSo), U2.7 (SDO)
Enable: P1.4, R3.1; also elsewhere on the board
GND: DPad1.5 (Common), P1.2, P1.5, P1.7, P2.1, P3.4 (GND), P3.5 (shield), P4.1, Q4.2 (E), R3.2, SW_A1.1, SW_B1.1, SW_Select1.1, SW_Shoulder_L1.1, SW_Shoulder_R1.1, SW_Start1.1, SW_X1.1, SW_Y1.1, U1.6 (Gnd), U1.9 (Gnd), U1.14 (Gnd), U1.20 (Gnd), U1.25 (Gnd), U1.30 (Gnd), U1.34 (Gnd), U1.39 (Gnd), U2.1 (Gnd), U2.8 (Gnd); also elsewhere on the board
unnamed: P2.3, U1.3 (SDA)
unnamed: P2.4, U1.5 (SCL)
unnamed: P2.5, U1.11 (SPI0_CE1)
unnamed: P4.2, U1.8 (TXD)
unnamed: P4.3, U1.10 (RXD)
unnamed: Q4.1 (B), R5.1
unnamed: Q4.3 (C), R7.2, R8.2, R9.2, R10.2
unnamed: R6.1, U2.2 (Reset)
unnamed: R7.1, U2.11 (LED_K1)
unnamed: R8.1, U2.12 (LED_K2)
unnamed: R9.1, U2.13 (LED_K3)
unnamed: R10.1, U2.14 (LED_K4)
unnamed: U1.22 (BCM_25), U2.4 (D/CX)
unnamed: U1.24 (SPI0_CE0), U2.5 (CSX)

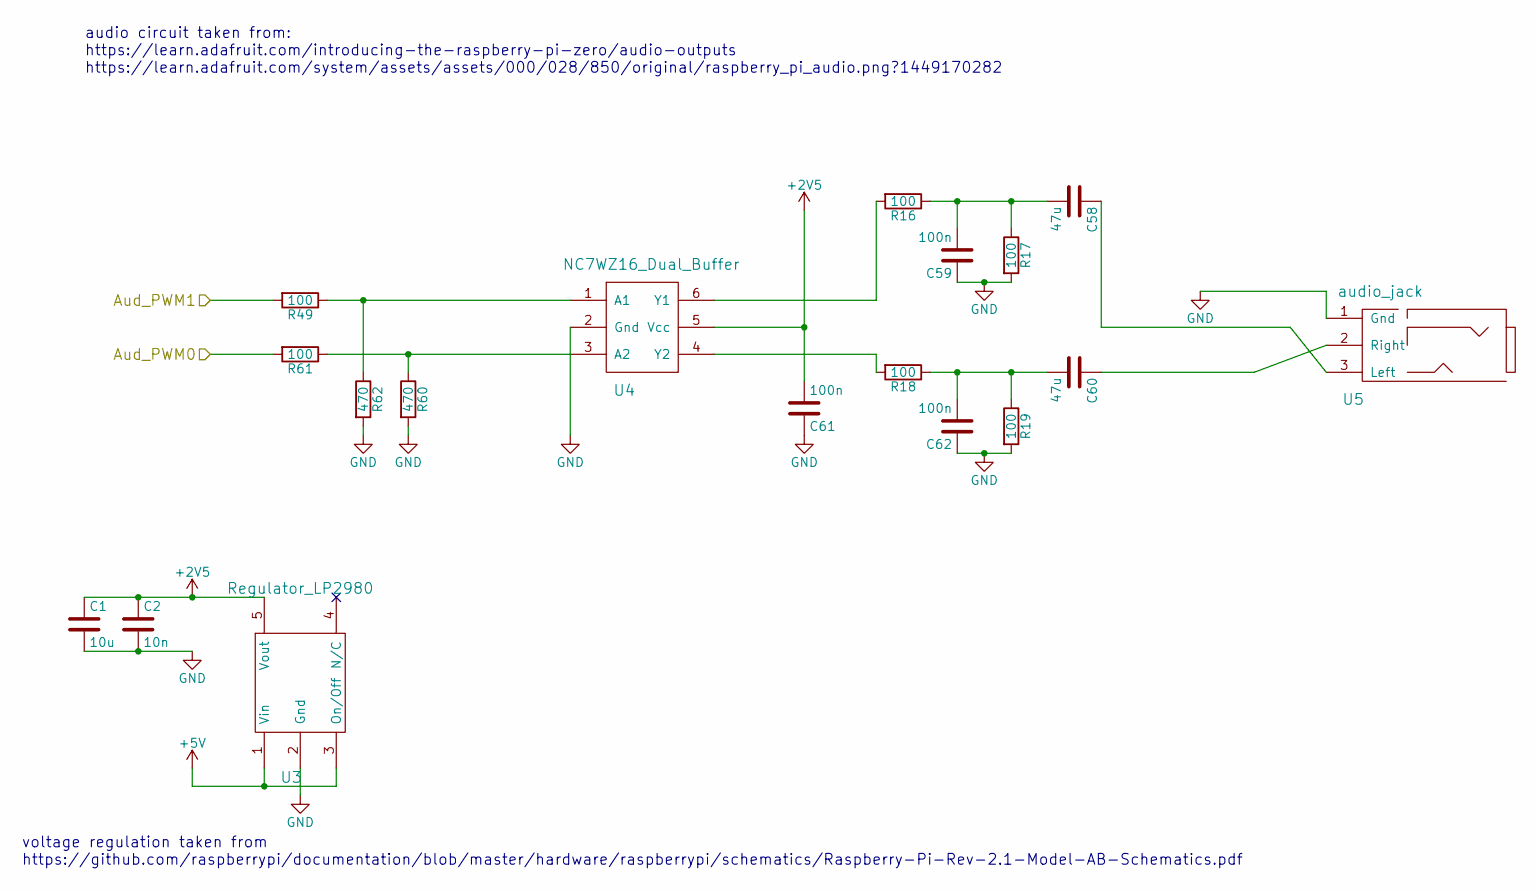
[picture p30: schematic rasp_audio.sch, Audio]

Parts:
C1: 10u; C_0805_HandSoldering; ManufacturerPartNumber VJ0805G106KXQTW1BC
C2: 10n; C_0805_HandSoldering; ManufacturerPartNumber VJ0805Y103JXQCW1BC
C58, C60: 47u; C_0805_HandSoldering; ManufacturerPartNumber VJ0805V475MXQTW1BC
C59, C61, C62: 100n; C_0805_HandSoldering; ManufacturerPartNumber VJ0805V104ZXQCW1BC
R16, R17, R18, R19, R49, R61: 100; R_0805_HandSoldering; ManufacturerPartNumber ERJ-6ENF1000V
R60, R62: 470; R_0805_HandSoldering; ManufacturerPartNumber ERJ-6ENF4700V
U3: Regulator_LP2980; SOT-23-5; ManufacturerPartNumber LP2980AIM5-2.5/NOPB
U4: NC7WZ16_Dual_Buffer; SC-70-6_Handsoldering; ManufacturerPartNumber NC7WZ16P6X
U5: audio_jack; audio_smd_SJ-3523-SMT-TR; ManufacturerPartNumber SJ-3523-SMT-TR

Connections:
+2V5: C1.1, C2.1, C61.2, U3.5 (Vout), U4.5 (Vcc)
+5V: U3.1 (Vin), U3.3 (On/Off); also elsewhere on the board
/Rasberppy B+ audio/Aud_PWM0: R61.2; also elsewhere on the board
/Rasberppy B+ audio/Aud_PWM1: R49.2; also elsewhere on the board
GND: C1.2, C2.2, C59.1, C61.1, C62.1, R17.2, R19.2, R60.2, R62.2, U3.2 (Gnd), U4.2 (Gnd), U5.1 (Gnd); also elsewhere on the board
unnamed: C58.1, U5.3 (Left)
unnamed: C58.2, C59.2, R16.1, R17.1
unnamed: C60.1, U5.2 (Right)
unnamed: C60.2, C62.2, R18.1, R19.1
unnamed: R16.2, U4.6 (Y1)
unnamed: R18.2, U4.4 (Y2)
unnamed: R49.1, R62.1, U4.1 (A1)
unnamed: R60.1, R61.1, U4.3 (A2)

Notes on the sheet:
voltage regulation taken from https://github.com/raspberrypi/documentation/blob/master/hardware/raspberrypi/schematics/Raspberry-Pi-Rev-2.1-Model-AB-Schematics.pdf
audio circuit taken from: https://learn.adafruit.com/introducing-the-raspberry-pi-zero/audio-outputs https://learn.adafruit.com/system/assets/assets/000/028/850/original/raspberry_pi_audio.png?1449170282

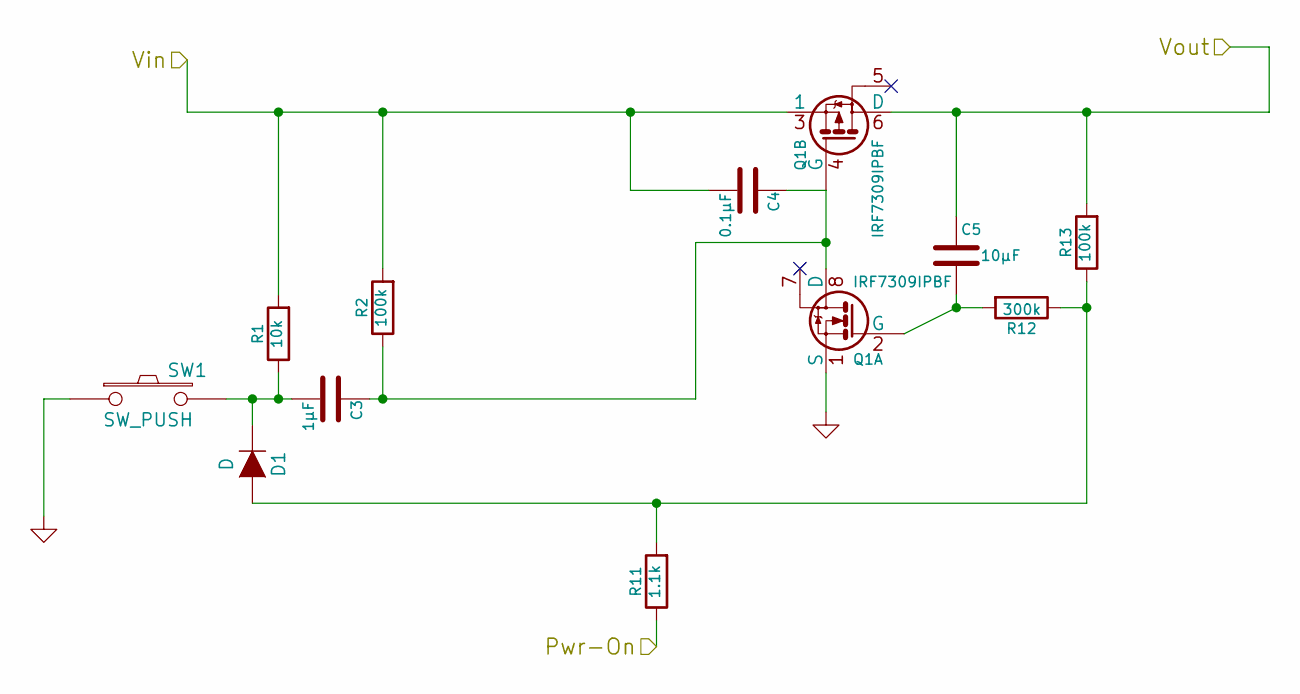
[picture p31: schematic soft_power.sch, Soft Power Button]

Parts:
C3: 1µF; C_0805_HandSoldering; ManufacturerPartNumber VJ0805Y105KXQTW1BC
C4: 0.1µF; C_0805_HandSoldering; ManufacturerPartNumber 885012207098
C5: 10µF; C_0805_HandSoldering; ManufacturerPartNumber VJ0805G106KXQTW1BC
D1: D; SOD-123; ManufacturerPartNumber 1N4148W-TP
Q1: IRF7309IPBF; SOIC-8-N; ManufacturerPartNumber IRF7309PBF
R1: 10k; R_0805_HandSoldering; ManufacturerPartNumber ERJ-6ENF1002V
R2, R13: 100k; R_0805_HandSoldering; ManufacturerPartNumber ERJ-6ENF1003V
R11: 1.1k; R_0805_HandSoldering; ManufacturerPartNumber ERJ-6ENF1101V
R12: 300k; R_0805_HandSoldering; ManufacturerPartNumber ERJ-6ENF3003V
SW1: SW_PUSH; btn_1571262-1; ManufacturerPartNumber 1571262-1

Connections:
+BATT: C4.2, Q1.3 (1), R1.2, R2.2; also elsewhere on the board
/soft_power_button/Pwr-On: R11.1; also elsewhere on the board
Enable: C5.2, Q1.6 (D), R13.2; also elsewhere on the board
GND: Q1.1 (S), SW1.1; also elsewhere on the board
unnamed: C3.1, C4.1, Q1.4 (G), Q1.8 (D), R2.1
unnamed: C3.2, D1.1 (K), R1.1, SW1.2
unnamed: C5.1, Q1.2 (G), R12.2
unnamed: D1.2 (A), R11.2, R12.1, R13.1

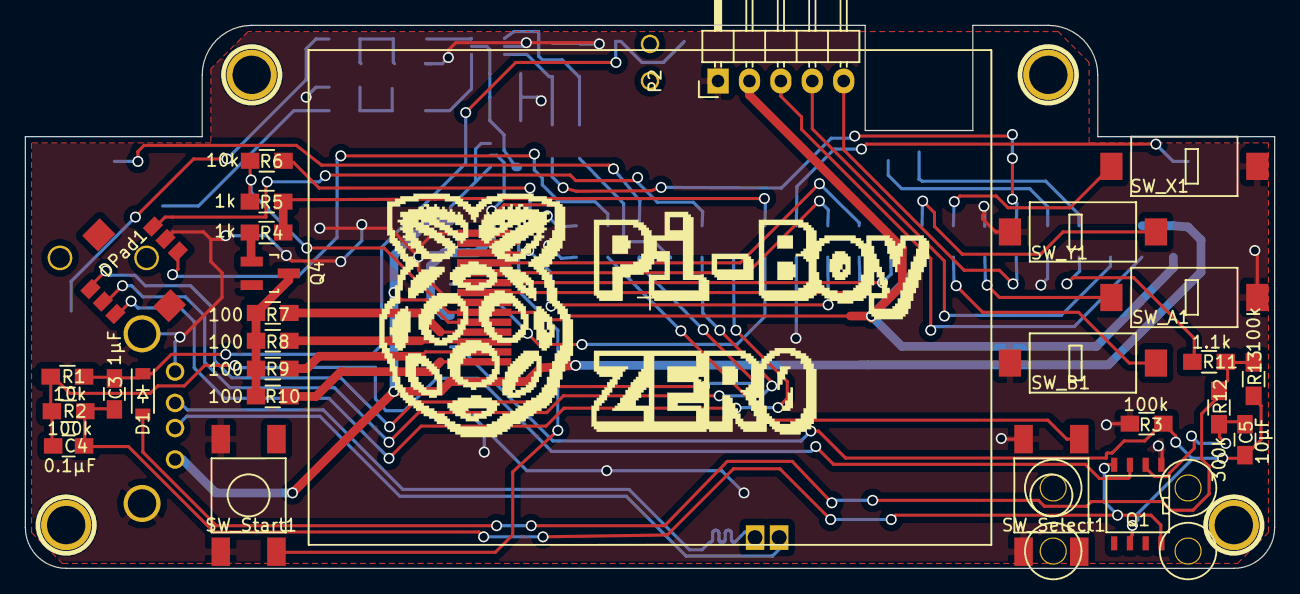
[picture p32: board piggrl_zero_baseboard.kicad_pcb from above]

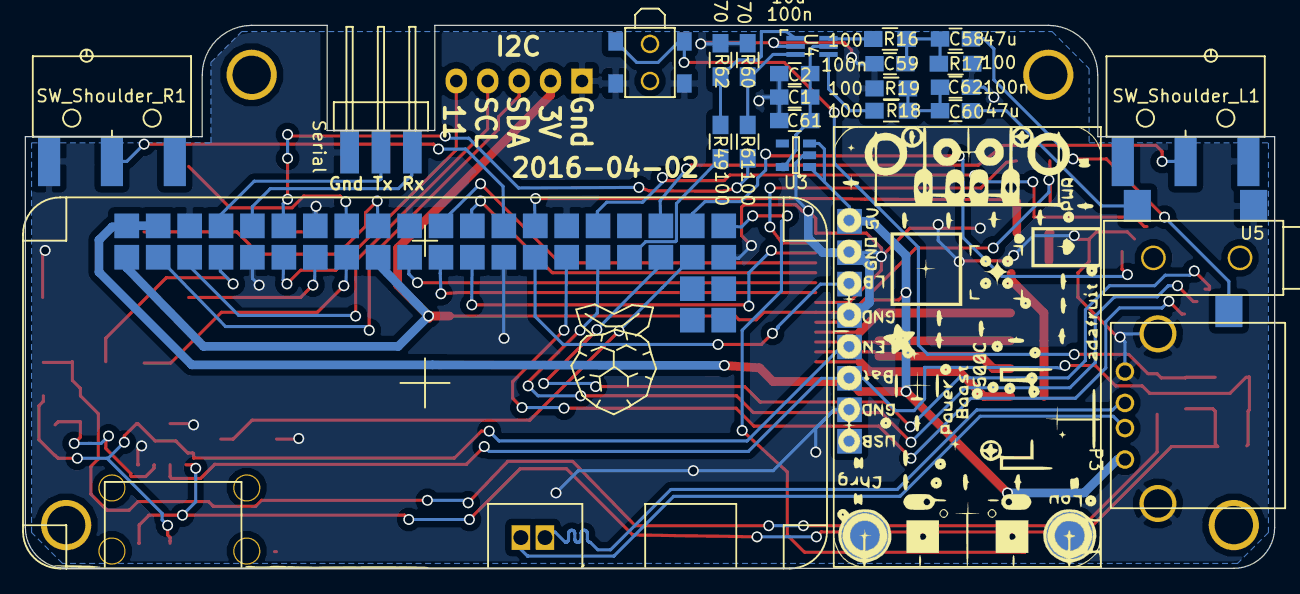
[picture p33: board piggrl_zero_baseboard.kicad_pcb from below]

Board: 2 copper layers, 101.0 x 43.9 mm, 57 parts (25 on the bottom side), 55 nets.

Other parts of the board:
1PIN, 1PIN#2, 1PIN#3, 1PIN#4: P***; 1pin

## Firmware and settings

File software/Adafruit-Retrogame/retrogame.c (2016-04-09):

/*
ADAFRUIT RETROGAME UTILITY: remaps buttons on Raspberry Pi GPIO header
to virtual USB keyboard presses.  Great for classic game emulators!
Retrogame is interrupt-driven and efficient (usually under 0.3% CPU use)
and debounces inputs for glitch-free gaming.

Connect one side of button(s) to GND pin (there are several on the GPIO
header, but see later notes) and the other side to GPIO pin of interest.
Internal pullups are used; no resistors required.  Avoid pins 8 and 10;
these are configured as a serial port by default on most systems (this
can be disabled but takes some doing).  Pin configuration is currently
set in global table; no config file yet.  See later comments.

Must be run as root, i.e. 'sudo ./retrogame &' or configure init scripts
to launch automatically at system startup.

Requires uinput kernel module.  This is typically present on popular
Raspberry Pi Linux distributions but not enabled on some older varieties.
To enable, either type:

    sudo modprobe uinput

Or, to make this persistent between reboots, add a line to /etc/modules:

    uinput

Prior versions of this code, when being compiled for use with the Cupcade
or PiGRRL projects, required CUPCADE to be #defined.  This is no longer
the case; instead a test is performed to see if a PiTFT is connected, and
one of two I/O tables is automatically selected.

Written by Phil Burgess for Adafruit Industries, distributed under BSD
License.  Adafruit invests time and resources providing this open source
code, please support Adafruit and open-source hardware by purchasing
products from Adafruit!


Copyright (c) 2013 Adafruit Industries.
All rights reserved.

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
- Redistributions of source code must retain the above copyright notice,
  this list of conditions and the following disclaimer.
- Redistributions in binary form must reproduce the above copyright notice,
  this list of conditions and the following disclaimer in the documentation
  and/or other materials provided with the distribution.

THIS SOFTWARE IS PROVIDED BY THE COPYRIGHT HOLDERS AND CONTRIBUTORS "AS IS"
AND ANY EXPRESS OR IMPLIED WARRANTIES, INCLUDING, BUT NOT LIMITED TO, THE
IMPLIED WARRANTIES OF MERCHANTABILITY AND FITNESS FOR A PARTICULAR PURPOSE
ARE DISCLAIMED. IN NO EVENT SHALL THE COPYRIGHT HOLDER OR CONTRIBUTORS BE
LIABLE FOR ANY DIRECT, INDIRECT, INCIDENTAL, SPECIAL, EXEMPLARY, OR
CONSEQUENTIAL DAMAGES (INCLUDING, BUT NOT LIMITED TO, PROCUREMENT OF
SUBSTITUTE GOODS OR SERVICES; LOSS OF USE, DATA, OR PROFITS; OR BUSINESS
INTERRUPTION) HOWEVER CAUSED AND ON ANY THEORY OF LIABILITY, WHETHER IN
CONTRACT, STRICT LIABILITY, OR TORT (INCLUDING NEGLIGENCE OR OTHERWISE)
ARISING IN ANY WAY OUT OF THE USE OF THIS SOFTWARE, EVEN IF ADVISED OF THE
POSSIBILITY OF SUCH DAMAGE.
*/

#include <stdio.h>
#include <stdlib.h>
#include <string.h>
#include <unistd.h>
#include <fcntl.h>
#include <poll.h>
#include <signal.h>
#include <sys/mman.h>
#include <linux/input.h>
#include <linux/uinput.h>


// START HERE ------------------------------------------------------------
// This table remaps GPIO inputs to keyboard values.  In this initial
// implementation there's a 1:1 relationship (can't attach multiple keys
// to a button) and the list is fixed in code; there is no configuration
// file.  Buttons physically connect between GPIO pins and ground.  There
// are only a few GND pins on the GPIO header, so a breakout board is
// often needed.  If you require just a couple extra ground connections
// and have unused GPIO pins, set the corresponding key value to GND to
// create a spare ground point.

#define GND -1
struct {
	int pin;
	int key;
} *io, // In main() this pointer is set to one of the two tables below.
   ioStandard[] = {
	// Input   Output (from /usr/include/linux/input.h)
        // Pin numbers are the BCM ones, not the physical pineader numbers
	{  23,     KEY_A       }, // X (SNES: blue)
	{  24,     KEY_S       }, // Y (SNES: green)
	{  27,     KEY_Z       }, // A (SNES: red)
	{  22,     KEY_X       }, // B (SNES: yellow)
	{  16,     KEY_Q       }, // shoulder left
	{   7,     KEY_W       }, // shoulder right 
	{  21,     KEY_ENTER   }, // start (left of tft)
	{  26,     KEY_SPACE   }, // select (right of tft)
	{  12,     KEY_UP      }, // dpad up
	{   5,     KEY_DOWN    }, // dpad down
	{  19,     KEY_LEFT    }, // dpad left
	{  20,     KEY_RIGHT   }, // dpad right
	{   6,     KEY_C       }, // dpad click
	// For credit/start/etc., use USB keyboard or add more buttons.
	{  -1,     -1           } }; // END OF LIST, DO NOT CHANGE

// A "Vulcan nerve pinch" (holding down a specific button combination
// for a few seconds) issues an 'esc' keypress to MAME (which brings up
// an exit menu or quits the current game).  The button combo is
// configured with a bitmask corresponding to elements in the above io[]
// array.  The default value here uses elements 6 and 7 (start and select
// in the Cupcade pinout).  If you change this, make certain it's a combo
// that's not likely to occur during actual gameplay (i.e. avoid using
// joystick directions or hold-for-rapid-fire buttons).
// Also key auto-repeat times are set here.  This is for navigating the
// game menu using the 'gamera' utility; MAME disregards key repeat
// events (as it should).
const unsigned long vulcanMask = (1L << 6) | (1L << 7);
const int           vulcanKey  = KEY_ESC, // Keycode to send
                    vulcanTime = 1500,    // Pinch time in milliseconds
                    repTime1   = 500,     // Key hold time to begin repeat
                    repTime2   = 100;     // Time between key repetitions


// A few globals ---------------------------------------------------------

char
  *progName,                         // Program name (for error reporting)
   sysfs_root[] = "/sys/class/gpio", // Location of Sysfs GPIO files
   running      = 1;                 // Signal handler will set to 0 (exit)
volatile unsigned int
  *gpio;                             // GPIO register table
const int
   debounceTime = 20;                // 20 ms for button debouncing


// Some utility functions ------------------------------------------------

// Set one GPIO pin attribute through the Sysfs interface.
int pinConfig(int pin, char *attr, char *value) {
	char filename[50];
	int  fd, w, len = strlen(value);
	sprintf(filename, "%s/gpio%d/%s", sysfs_root, pin, attr);
	if((fd = open(filename, O_WRONLY)) < 0) return -1;
	w = write(fd, value, len);
	close(fd);
	return (w != len); // 0 = success
}

// Un-export any Sysfs pins used; don't leave filesystem cruft.  Also
// restores any GND pins to inputs.  Write errors are ignored as pins
// may be in a partially-initialized state.
void cleanup() {
	char buf[50];
	int  fd, i;
	sprintf(buf, "%s/unexport", sysfs_root);
	if((fd = open(buf, O_WRONLY)) >= 0) {
		for(i=0; io[i].pin >= 0; i++) {
			// Restore GND items to inputs
			if(io[i].key == GND)
				pinConfig(io[i].pin, "direction", "in");
			// And un-export all items regardless
			sprintf(buf, "%d", io[i].pin);
			write(fd, buf, strlen(buf));
		}
		close(fd);
	}
}

// Quick-n-dirty error reporter; print message, clean up and exit.
void err(char *msg) {
	printf("%s: %s.  Try 'sudo %s'.\n", progName, msg, progName);
	cleanup();
	exit(1);
}

// Interrupt handler -- set global flag to abort main loop.
void signalHandler(int n) {
	running = 0;
}

// Detect Pi board type.  Doesn't return super-granular details,
// just the most basic distinction needed for GPIO compatibility:
// 0: Pi 1 Model B revision 1
// 1: Pi 1 Model B revision 2, Model A, Model B+, Model A+
// 2: Pi 2 Model B

static int boardType(void) {
	FILE *fp;
	char  buf[1024], *ptr;
	int   n, board = 1; // Assume Pi1 Rev2 by default

	return 1; // the pi-zero equals a B+

	// Relies on info in /proc/cmdline.  If this becomes unreliable
	// in the future, alt code below uses /proc/cpuinfo if any better.
#if 1
	if((fp = fopen("/proc/cmdline", "r"))) {
		while(fgets(buf, sizeof(buf), fp)) {
			if((ptr = strstr(buf, "mem_size=")) &&
			   (sscanf(&ptr[9], "%x", &n) == 1) &&
			   (n == 0x3F000000)) {
				board = 2; // Appears to be a Pi 2
				break;
			} else if((ptr = strstr(buf, "boardrev=")) &&
			          (sscanf(&ptr[9], "%x", &n) == 1) &&
			          ((n == 0x02) || (n == 0x03))) {
				board = 0; // Appears to be an early Pi
				break;
			}
		}
		fclose(fp);
	}
#else
	char s[8];
	if((fp = fopen("/proc/cpuinfo", "r"))) {
		while(fgets(buf, sizeof(buf), fp)) {
			if((ptr = strstr(buf, "Hardware")) &&
			   (sscanf(&ptr[8], " : %7s", s) == 1) &&
			   (!strcmp(s, "BCM2709"))) {
				board = 2; // Appears to be a Pi 2
				break;
			} else if((ptr = strstr(buf, "Revision")) &&
			          (sscanf(&ptr[8], " : %x", &n) == 1) &&
			          ((n == 0x02) || (n == 0x03))) {
				board = 0; // Appears to be an early Pi
				break;
			}
		}
		fclose(fp);
	}
#endif

	return board;
}

// Main stuff ------------------------------------------------------------

#define PI1_BCM2708_PERI_BASE 0x20000000
#define PI1_GPIO_BASE         (PI1_BCM2708_PERI_BASE + 0x200000)
#define PI2_BCM2708_PERI_BASE 0x3F000000
#define PI2_GPIO_BASE         (PI2_BCM2708_PERI_BASE + 0x200000)
#define BLOCK_SIZE            (4*1024)
#define GPPUD                 (0x94 / 4)
#define GPPUDCLK0             (0x98 / 4)

int main(int argc, char *argv[]) {

	// A few arrays here are declared with 32 elements, even though
	// values aren't needed for io[] members where the 'key' value is
	// GND.  This simplifies the code a bit -- no need for mallocs and
	// tests to create these arrays -- but may waste a handful of
	// bytes for any declared GNDs.
	char                   buf[50],      // For sundry filenames
	                       c,            // Pin input value ('0'/'1')
	                       board;        // 0=Pi1Rev1, 1=Pi1Rev2, 2=Pi2
	int                    fd,           // For mmap, sysfs, uinput
	                       i, j,         // Asst. counter
	                       bitmask,      // Pullup enable bitmask
	                       timeout = -1, // poll() timeout
	                       intstate[32], // Last-read state
	                       extstate[32], // Debounced state
	                       lastKey = -1; // Last key down (for repeat)
	unsigned long          bitMask, bit; // For Vulcan pinch detect
	volatile unsigned char shortWait;    // Delay counter
	struct input_event     keyEv, synEv; // uinput events
	struct pollfd          p[32];        // GPIO file descriptors

	progName = argv[0];             // For error reporting
	signal(SIGINT , signalHandler); // Trap basic signals (exit cleanly)
	signal(SIGKILL, signalHandler);

	// Select io[] table for Cupcade (TFT) or 'normal' project.
	io = ioStandard;
	    /*(access("/etc/modprobe.d/adafruit.conf", F_OK) ||
	      access("/dev/fb1", F_OK)) ? ioStandard : ioTFT;*/

	// If this is a "Revision 1" Pi board (no mounting holes),
	// remap certain pin numbers in the io[] array for compatibility.
	// This way the code doesn't need modification for old boards.
	board = boardType();
	if(board == 0) {
		for(i=0; io[i].pin >= 0; i++) {
			if(     io[i].pin ==  2) io[i].pin = 0;
			else if(io[i].pin ==  3) io[i].pin = 1;
			else if(io[i].pin == 27) io[i].pin = 21;
		}
	}

	// ----------------------------------------------------------------
	// Although Sysfs provides solid GPIO interrupt handling, there's
	// no interface to the internal pull-up resistors (this is by
	// design, being a hardware-dependent feature).  It's necessary to
	// grapple with the GPIO configuration registers directly to enable
	// the pull-ups.  Based on GPIO example code by Dom and Gert van
	// Loo on elinux.org

	if((fd = open("/dev/mem", O_RDWR | O_SYNC)) < 0)
		err("Can't open /dev/mem");
	gpio = mmap(            // Memory-mapped I/O
	  NULL,                 // Any adddress will do
	  BLOCK_SIZE,           // Mapped block length
	  PROT_READ|PROT_WRITE, // Enable read+write
	  MAP_SHARED,           // Shared with other processes
	  fd,                   // File to map
	  (board == 2) ?
	   PI2_GPIO_BASE :      // -> GPIO registers
	   PI1_GPIO_BASE);

	close(fd);              // Not needed after mmap()
	if(gpio == MAP_FAILED) err("Can't mmap()");
	// Make combined bitmap of pullup-enabled pins:
	for(bitmask=i=0; io[i].pin >= 0; i++)
		if(io[i].key != GND) bitmask |= (1 << io[i].pin);
	gpio[GPPUD]     = 2;                    // Enable pullup
	for(shortWait=150;--shortWait;);        // Min 150 cycle wait
	gpio[GPPUDCLK0] = bitmask;              // Set pullup mask
	for(shortWait=150;--shortWait;);        // Wait again
	gpio[GPPUD]     = 0;                    // Reset pullup registers
	gpio[GPPUDCLK0] = 0;
	(void)munmap((void *)gpio, BLOCK_SIZE); // Done with GPIO mmap()


	// ----------------------------------------------------------------
	// All other GPIO config is handled through the sysfs interface.

	sprintf(buf, "%s/export", sysfs_root);
	if((fd = open(buf, O_WRONLY)) < 0) // Open Sysfs export file
		err("Can't open GPIO export file");
	for(i=j=0; io[i].pin >= 0; i++) { // For each pin of interest...
		sprintf(buf, "%d", io[i].pin);
		write(fd, buf, strlen(buf));             // Export pin
		pinConfig(io[i].pin, "active_low", "0"); // Don't invert
		if(io[i].key == GND) {
			// Set pin to output, value 0 (ground)
			if(pinConfig(io[i].pin, "direction", "out") ||
			   pinConfig(io[i].pin, "value"    , "0"))
				err("Pin config failed (GND)");
		} else {
			// Set pin to input, detect rise+fall events
			if(pinConfig(io[i].pin, "direction", "in") ||
			   pinConfig(io[i].pin, "edge"     , "both"))
			  {
			    printf("error with %d\n", io[i].pin);
			    err("Pin config failed");
			  }
			// Get initial pin value
			sprintf(buf, "%s/gpio%d/value",
			  sysfs_root, io[i].pin);
			// The p[] file descriptor array isn't necessarily
			// aligned with the io[] array.  GND keys in the
			// latter are skipped, but p[] requires contiguous
			// entries for poll().  So the pins to monitor are
			// at the head of p[], and there may be unused
			// elements at the end for each GND.  Same applies
			// to the intstate[] and extstate[] arrays.
			if((p[j].fd = open(buf, O_RDONLY)) < 0)
				err("Can't access pin value");
			intstate[j] = 0;
			if((read(p[j].fd, &c, 1) == 1) && (c == '0'))
				intstate[j] = 1;
			extstate[j] = intstate[j];
			p[j].events  = POLLPRI; // Set up poll() events
			p[j].revents = 0;
			j++;
		}
	} // 'j' is now count of non-GND items in io[] table
	close(fd); // Done exporting


	// ----------------------------------------------------------------
	// Set up uinput

#if 1
	// Retrogame normally uses /dev/uinput for generating key events.
	// Cupcade requires this and it's the default.  SDL2 (used by
	// some newer emulators) doesn't like it, wants /dev/input/event0
	// instead.  Enable that code by changing to "#if 0" above.
	if((fd = open("/dev/uinput", O_WRONLY | O_NONBLOCK)) < 0)
		err("Can't open /dev/uinput");
	if(ioctl(fd, UI_SET_EVBIT, EV_KEY) < 0)
		err("Can't SET_EVBIT");
	for(i=0; io[i].pin >= 0; i++) {
		if(io[i].key != GND) {
			if(ioctl(fd, UI_SET_KEYBIT, io[i].key) < 0)
				err("Can't SET_KEYBIT");
		}
	}
	if(ioctl(fd, UI_SET_KEYBIT, vulcanKey) < 0) err("Can't SET_KEYBIT");
	struct uinput_user_dev uidev;
	memset(&uidev, 0, sizeof(uidev));
	snprintf(uidev.name, UINPUT_MAX_NAME_SIZE, "retrogame");
	uidev.id.bustype = BUS_USB;
	uidev.id.vendor  = 0x1;
	uidev.id.product = 0x1;
	uidev.id.version = 1;
	if(write(fd, &uidev, sizeof(uidev)) < 0)
		err("write failed");
	if(ioctl(fd, UI_DEV_CREATE) < 0)
		err("DEV_CREATE failed");
#else // SDL2 prefers this event methodology
	if((fd = open("/dev/input/event0", O_WRONLY | O_NONBLOCK)) < 0)
		err("Can't open /dev/input/event0");
#endif

	// Initialize input event structures
	memset(&keyEv, 0, sizeof(keyEv));
	keyEv.type  = EV_KEY;
	memset(&synEv, 0, sizeof(synEv));
	synEv.type  = EV_SYN;
	synEv.code  = SYN_REPORT;
	synEv.value = 0;

	// 'fd' is now open file descriptor for issuing uinput events


	// ----------------------------------------------------------------
	// Monitor GPIO file descriptors for button events.  The poll()
	// function watches for GPIO IRQs in this case; it is NOT
	// continually polling the pins!  Processor load is near zero.

	while(running) { // Signal handler can set this to 0 to exit
		// Wait for IRQ on pin (or timeout for button debounce)
		if(poll(p, j, timeout) > 0) { // If IRQ...
			for(i=0; i<j; i++) {       // Scan non-GND pins...
				if(p[i].revents) { // Event received?
					// Read current pin state, store
					// in internal state flag, but
					// don't issue to uinput yet --
					// must wait for debounce!
					lseek(p[i].fd, 0, SEEK_SET);
					read(p[i].fd, &c, 1);
					if(c == '0')      intstate[i] = 1;
					else if(c == '1') intstate[i] = 0;
					p[i].revents = 0; // Clear flag
				}
			}
			timeout = debounceTime; // Set timeout for debounce
			c       = 0;            // Don't issue SYN event
			// Else timeout occurred
		} else if(timeout == debounceTime) { // Button debounce timeout
			// 'j' (number of non-GNDs) is re-counted as
			// it's easier than maintaining an additional
			// remapping table or a duplicate key[] list.
			bitMask = 0L; // Mask of buttons currently pressed
			bit     = 1L;
			for(c=i=j=0; io[i].pin >= 0; i++, bit<<=1) {
				if(io[i].key != GND) {
					// Compare internal state against
					// previously-issued value.  Send
					// keystrokes only for changed states.
					if(intstate[j] != extstate[j]) {
						extstate[j] = intstate[j];
						keyEv.code  = io[i].key;
						keyEv.value = intstate[j];
						write(fd, &keyEv,
						  sizeof(keyEv));
						c = 1; // Follow w/SYN event
						if(intstate[j]) { // Press?
							// Note pressed key
							// and set initial
							// repeat interval.
							lastKey = i;
							timeout = repTime1;
						} else { // Release?
							// Stop repeat and
							// return to normal
							// IRQ monitoring
							// (no timeout).
							lastKey = timeout = -1;
						}
					}
					j++;
					if(intstate[i]) bitMask |= bit;
				}
			}

			// If the "Vulcan nerve pinch" buttons are pressed,
			// set long timeout -- if this time elapses without
			// a button state change, esc keypress will be sent.
			if((bitMask & vulcanMask) == vulcanMask)
				timeout = vulcanTime;
		} else if(timeout == vulcanTime) { // Vulcan timeout occurred
			// Send keycode (MAME exits or displays exit menu)
			keyEv.code = vulcanKey;
			for(i=1; i>= 0; i--) { // Press, release
				keyEv.value = i;
				write(fd, &keyEv, sizeof(keyEv));
				usleep(10000); // Be slow, else MAME flakes
				write(fd, &synEv, sizeof(synEv));
				usleep(10000);
			}
			timeout = -1; // Return to normal processing
			c       = 0;  // No add'l SYN required
		} else if(lastKey >= 0) { // Else key repeat timeout
			if(timeout == repTime1) timeout = repTime2;
			else if(timeout > 30)   timeout -= 5; // Accelerate
			c           = 1; // Follow w/SYN event
			keyEv.code  = io[lastKey].key;
			keyEv.value = 2; // Key repeat event
			write(fd, &keyEv, sizeof(keyEv));
		}
		if(c) write(fd, &synEv, sizeof(synEv));
	}

	// ----------------------------------------------------------------
	// Clean up

	ioctl(fd, UI_DEV_DESTROY); // Destroy and
	close(fd);                 // close uinput
	cleanup();                 // Un-export pins

	puts("Done.");

	return 0;
}

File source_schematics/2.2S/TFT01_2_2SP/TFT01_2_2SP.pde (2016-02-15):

/*==========================================================================
The LCD connection is the same as Nokia LCD5110 and  is a“8 Bit Pant Demo“

Just for ElecFreaks TFT01-2.2SP, which use SPI serial port and 240x320 pixel.
The driver is ILI9341.
 
by Elecfreaks
==========================================================================*/ 
#include "pins_arduino.h"

#define LCD_WR    9   //SCL
#define LCD_RS   10   //SDA
#define LCD_DC   11   //A0
#define LCD_REST 12   //RESET
#define LCD_CS   13   //CSE    

volatile uint8_t *P_SCK, *P_MOSI, *P_DC, *P_RST, *P_CS;
volatile uint8_t B_SCK, B_MOSI, B_DC, B_RST, B_CS;
  
void LCD_Writ_Bus(char data)
{
  *P_CS &= ~B_CS;
  for (unsigned char c=0; c<8; c++)
  {
	if (data & 0x80)
		*P_MOSI |= B_MOSI;
	else
		*P_MOSI &= ~B_MOSI;
	data = data<<1;
	*P_SCK &= ~B_SCK;
	asm ("nop");
	*P_SCK |= B_SCK;
  }
  *P_CS |= B_CS;
}
 
void LCD_Write_COM(char VL)  
{   
  digitalWrite(LCD_DC,LOW);
  LCD_Writ_Bus(VL);
}
 
void LCD_Write_DATA(char VL)    
{
  digitalWrite(LCD_DC,HIGH);
  LCD_Writ_Bus(VL);
}
 
void Address_set(unsigned int x1,unsigned int y1,unsigned int x2,unsigned int y2)
{
   LCD_Write_COM(0x2a);
   LCD_Write_DATA(x1>>8);
   LCD_Write_DATA(x1);
   LCD_Write_DATA(x2>>8);
   LCD_Write_DATA(x2);
  
   LCD_Write_COM(0x2b);
   LCD_Write_DATA(y1>>8);
   LCD_Write_DATA(y1);
   LCD_Write_DATA(y2>>8);
   LCD_Write_DATA(y2);

   LCD_Write_COM(0x2C);         				 
}
 
void LCD_Init(void)
{
        P_SCK	= portOutputRegister(digitalPinToPort(LCD_WR));
        B_SCK	= digitalPinToBitMask(LCD_WR);
	P_MOSI	= portOutputRegister(digitalPinToPort(LCD_RS));
	B_MOSI	= digitalPinToBitMask(LCD_RS);
	P_DC	= portOutputRegister(digitalPinToPort(LCD_DC));
	B_DC	= digitalPinToBitMask(LCD_DC);
	P_RST	= portOutputRegister(digitalPinToPort(LCD_REST));
	B_RST	= digitalPinToBitMask(LCD_REST);
	P_CS	= portOutputRegister(digitalPinToPort(LCD_CS));
	B_CS	= digitalPinToBitMask(LCD_CS);
 
        *P_RST &= ~B_RST;
	delay(10);
	*P_RST |= B_RST;
  
        LCD_Write_COM(0xCB);  
        LCD_Write_DATA(0x39); 
        LCD_Write_DATA(0x2C); 
        LCD_Write_DATA(0x00); 
        LCD_Write_DATA(0x34); 
        LCD_Write_DATA(0x02); 

        LCD_Write_COM(0xCF);  
        LCD_Write_DATA(0x00); 
        LCD_Write_DATA(0XC1); 
        LCD_Write_DATA(0X30); 

        LCD_Write_COM(0xE8);  
        LCD_Write_DATA(0x85); 
        LCD_Write_DATA(0x00); 
        LCD_Write_DATA(0x78); 

        LCD_Write_COM(0xEA);  
        LCD_Write_DATA(0x00); 
        LCD_Write_DATA(0x00); 
 
        LCD_Write_COM(0xED);  
        LCD_Write_DATA(0x64); 
        LCD_Write_DATA(0x03); 
        LCD_Write_DATA(0X12); 
        LCD_Write_DATA(0X81); 

        LCD_Write_COM(0xF7);  
        LCD_Write_DATA(0x20); 
  
        LCD_Write_COM(0xC0);    //Power control 
        LCD_Write_DATA(0x23);   //VRH[5:0] 
 
        LCD_Write_COM(0xC1);    //Power control 
        LCD_Write_DATA(0x10);   //SAP[2:0];BT[3:0] 

        LCD_Write_COM(0xC5);    //VCM control 
        LCD_Write_DATA(0x3e);   //Contrast
        LCD_Write_DATA(0x28); 
 
        LCD_Write_COM(0xC7);    //VCM control2 
        LCD_Write_DATA(0x86);   //--
 
        LCD_Write_COM(0x36);    // Memory Access Control 
        LCD_Write_DATA(0x48);   //C8	   //48 68竖屏//28 E8 横屏

        LCD_Write_COM(0x3A);    
        LCD_Write_DATA(0x55); 

        LCD_Write_COM(0xB1);    
        LCD_Write_DATA(0x00);  
        LCD_Write_DATA(0x18); 
 
        LCD_Write_COM(0xB6);    // Display Function Control 
        LCD_Write_DATA(0x08); 
        LCD_Write_DATA(0x82);
        LCD_Write_DATA(0x27);  
/* 
        LCD_Write_COM(0xF2);    // 3Gamma Function Disable 
        LCD_Write_DATA(0x00); 
 
        LCD_Write_COM(0x26);    //Gamma curve selected 
        LCD_Write_DATA(0x01); 

        LCD_Write_COM(0xE0);    //Set Gamma 
        LCD_Write_DATA(0x0F); 
        LCD_Write_DATA(0x31); 
        LCD_Write_DATA(0x2B); 
        LCD_Write_DATA(0x0C); 
        LCD_Write_DATA(0x0E); 
        LCD_Write_DATA(0x08); 
        LCD_Write_DATA(0x4E); 
        LCD_Write_DATA(0xF1); 
        LCD_Write_DATA(0x37); 
        LCD_Write_DATA(0x07); 
        LCD_Write_DATA(0x10); 
        LCD_Write_DATA(0x03); 
        LCD_Write_DATA(0x0E); 
        LCD_Write_DATA(0x09); 
        LCD_Write_DATA(0x00); 

        LCD_Write_COM(0XE1);    //Set Gamma 
        LCD_Write_DATA(0x00); 
        LCD_Write_DATA(0x0E); 
        LCD_Write_DATA(0x14); 
        LCD_Write_DATA(0x03); 
        LCD_Write_DATA(0x11); 
        LCD_Write_DATA(0x07); 
        LCD_Write_DATA(0x31); 
        LCD_Write_DATA(0xC1); 
        LCD_Write_DATA(0x48); 
        LCD_Write_DATA(0x08); 
        LCD_Write_DATA(0x0F); 
        LCD_Write_DATA(0x0C); 
        LCD_Write_DATA(0x31); 
        LCD_Write_DATA(0x36); 
        LCD_Write_DATA(0x0F); 
*/
        LCD_Write_COM(0x11);    //Exit Sleep 
        delay(120); 
				
        LCD_Write_COM(0x29);    //Display on 
        LCD_Write_COM(0x2c);   
}
 
void Pant(char VL)
{
  int i,j;
  Address_set(0,0,240,320);
  for(i=0;i<320;i++)
  {
    for (j=0;j<480;j++)
    {
      LCD_Write_DATA(VL);
    }
  }
}
 
void setup()
{
  unsigned char p;
  for(p=8;p<14;p++)
    pinMode(p,OUTPUT);
  LCD_Init();  
}
 
void loop()
{  
  Pant(0xFF);   
  Pant(0xF0);   
  Pant(0xE0);  
  Pant(0x05);  
  Pant(0x1F);    
  Pant(0x00);   
}

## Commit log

2016-02-15 push to github
    [LCD.obj, STARTUP.OBJ, font.obj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]
2016-02-18 added connection from low-bat on the powerboost to the (till now) unused ID_SD pin
    since we already used ID_SC for display-pwm, the whole board won't turn into an spec-compliant hat anyway...
    [piggrl_zero_baseboard.kicad_pcb, piggrl_zero_baseboard.sch, rasp_audio.sch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]
2016-03-03 fixed switched Value/Reference in soft_power schematic (showed in bad BOM references)
    [piggrl_zero_baseboard.kicad_pcb, piggrl_zero_baseboard.sch, rasp_audio.sch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]
2016-03-04 cleanup of silkscreen for better readability during assembly
    generated and pushed new boardfiles to oshpark
    [piggrl_zero_baseboard.kicad_pcb]
2016-03-05 added solder&test area highlight images
2016-03-05 fixed wrong transistor pinout on softpower p-mosfet
    common pinout is GSD and not DSG!
    [piggrl_zero_baseboard.kicad_pcb, piggrl_zero_baseboard.sch, rasp_audio.sch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]
2016-03-07 fixed mounting hole diameter which was slightly too small for an M3 screw
    [piggrl_zero_baseboard.kicad_pcb]
2016-03-07 fixed position of solder-holes to the usb-test-pads on the pi-zero
    [piggrl_zero_baseboard.kicad_pcb]
2016-03-07 added through-hole pads as clearance for the hdmi-connectors tabs on the raspberry-zero
    and rerouted some traces to make way
    [piggrl_zero_baseboard.kicad_pcb]
2016-03-07 added net_name to usb data lines and rerouted them on the pcb
    one less via, and usign kicads wonderfull differential-pair routing tool :-)
    [piggrl_zero_baseboard.kicad_pcb, piggrl_zero_baseboard.sch]
2016-03-10 bugfix: backlicht transistor pinout was BCE instead of common BEC
    [piggrl_zero_baseboard.kicad_pcb, piggrl_zero_baseboard.sch]
2016-03-10 ditch mosfet as softpower inverter and use same BJT transistor as the one used for the backlight
    [piggrl_zero_baseboard.kicad_pcb, piggrl_zero_baseboard.sch]
2016-03-10 turns out we don't need the transistor (Q3) at all... so remove it, leaving only the 100k pulldown on the powerboosts enable pin
    [piggrl_zero_baseboard.kicad_pcb, piggrl_zero_baseboard.sch]
2016-03-10 cleanup some traces
    and restore the accidentally deleted raspberry-footprint :-p
    [piggrl_zero_baseboard.kicad_pcb]
2016-03-11 replottet pcb that was fabbed, since plot of front copper layer was broken
    plottet version at 96a7204d41cedd91349ca2518c14b511f5b00693
2016-03-11 small script to do a visual diff on kicads pcb printouts (pdf)
2016-03-13 corrected usb-pad positions and mini-hdmi-tabs cutout based on 3d model
    [piggrl_zero_baseboard.kicad_pcb]
2016-03-13 added more 3d models
    [piggrl_zero_baseboard.kicad_pcb]
2016-03-13 added a nice 8bit-ish logo to the front silkscreen :-)
    ... that will be covered by the screen :'-(
    [piggrl_zero_baseboard.kicad_pcb]
2016-03-13 documented errors in revision 2016-02-13 and generated current board revision 2016-03-13 that has them fixed
2016-03-13 added pcb rendering in perfect-purple '#800080' and the gimp-file for the new front image
2016-03-14 added BOM for snapshot 2016-03-13
2016-04-02 fixed start/select button footprint
    commonly those push buttons pair their four pins the other way...
    [piggrl_zero_baseboard.kicad_pcb]
2016-04-09 added pwm-audio devicetree-overlays
2016-04-09 added 3dprintable case
    [button_ABXY.stl, button_dpad.stl, button_power.stl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]
2016-04-11 added print/build instructions
2016-05-12 added udev rule for retrogame
    for gpio-buttons to work with libretro retrogame needs to be configured by udev properly
2017-02-09 button overlay
2017-02-09 python powerbutton + systemd service-file
2017-02-09 remove unused stuff on current os (retropie 4.1)
2017-02-09 pi-blaster config, to be put in /etc/default/pi-blaster
    with settings for the display backlight PWM control
2017-02-10 emulation-station configuration for the piboy-zero (including retrogame input setting)
    [es_input.cfg, es_settings.cfg, es_systems.cfg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]
